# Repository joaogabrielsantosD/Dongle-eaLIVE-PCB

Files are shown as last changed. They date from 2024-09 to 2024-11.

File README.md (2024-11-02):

# Dongle-eaLIVE-PCB

## Hardware
Dongle-eaLIVE has been created using KiCad and all the design files can be found under [01_Specs](01_Specs/) folder (you can see in this folder the [Schematic](01_Specs/01_Schematic/), [LayoutPCB](01_Specs/02_LayoutPCB/) and [3Dmodel](01_Specs/03_3Dmodel/)) , and the  production can be found in [Gerber](02_Gerber&BOM/01_Gerber/) files and the interactive BOM in [BOM](02_Gerber&BOM/02_BOM/00_InteractiveBOM/). Images below shows a quick overview of the hardware design.

| PCB Front |  PCB Back |
| :---: | :---: |
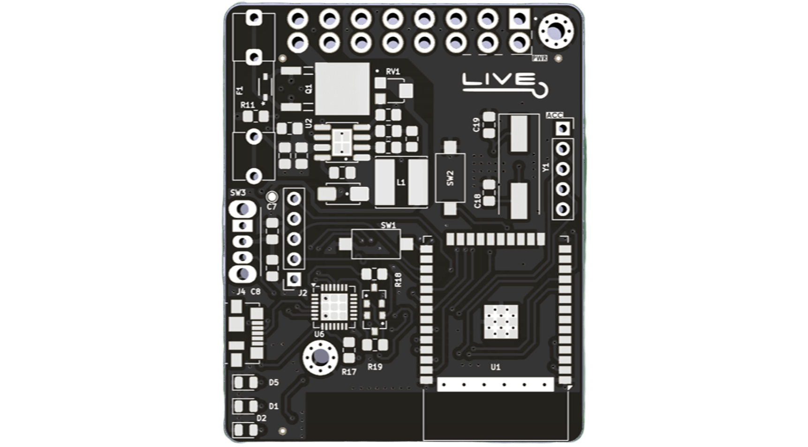
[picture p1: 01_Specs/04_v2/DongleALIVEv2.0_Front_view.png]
Dongle-ealive front
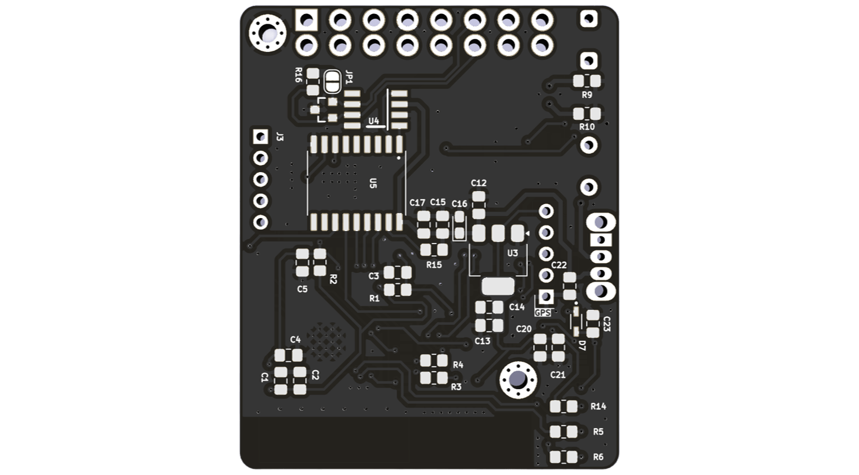
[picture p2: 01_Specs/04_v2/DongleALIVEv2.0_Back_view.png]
Dongle-eavlive back
|   |  |

### Dimensions
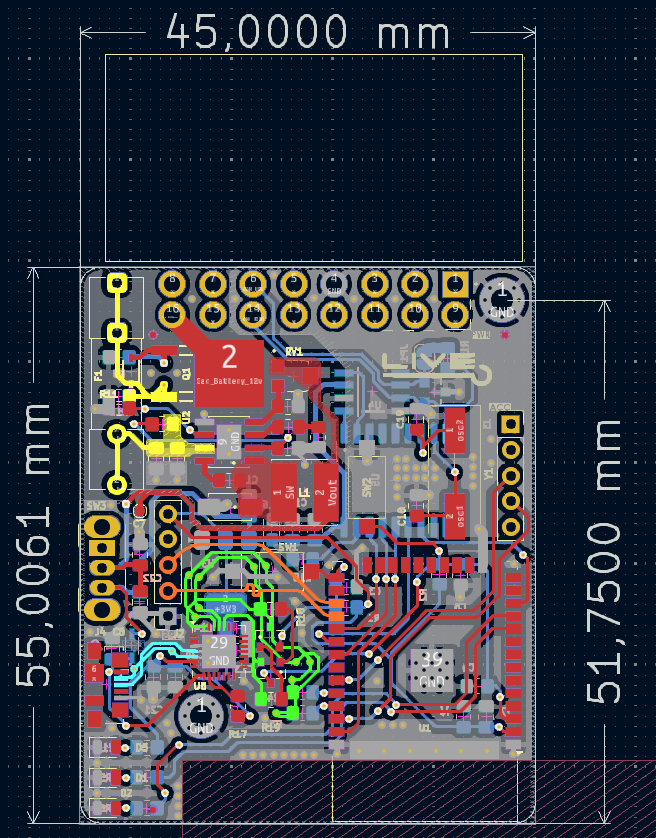
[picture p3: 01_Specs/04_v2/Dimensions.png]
Dongle-ealive dimensions


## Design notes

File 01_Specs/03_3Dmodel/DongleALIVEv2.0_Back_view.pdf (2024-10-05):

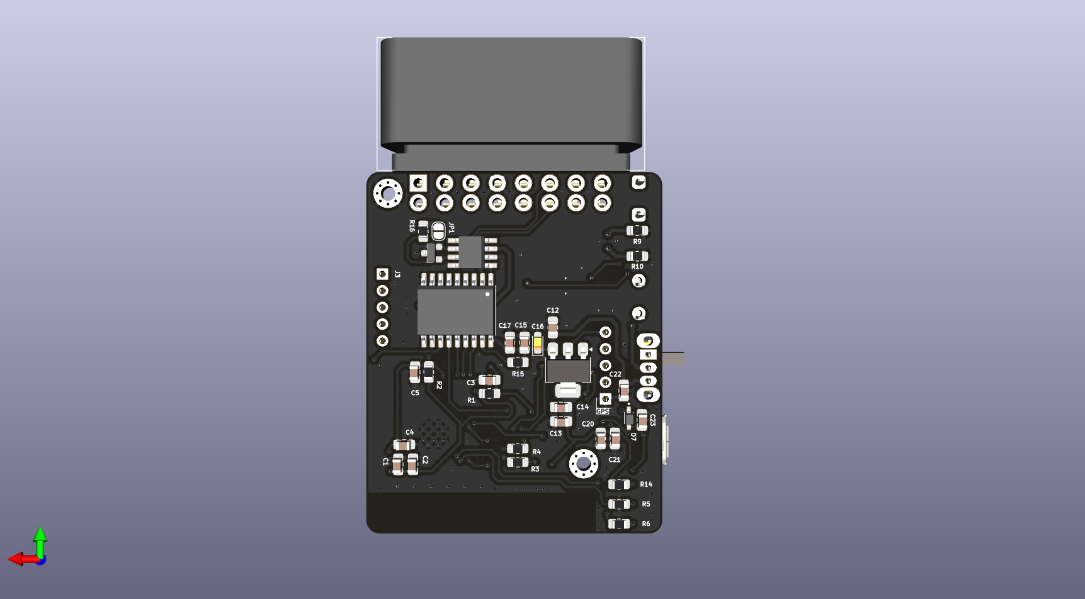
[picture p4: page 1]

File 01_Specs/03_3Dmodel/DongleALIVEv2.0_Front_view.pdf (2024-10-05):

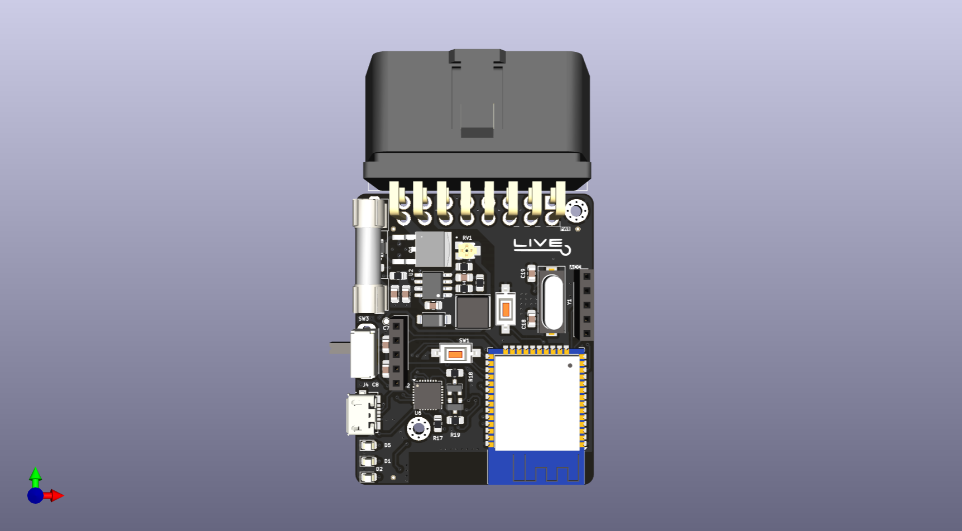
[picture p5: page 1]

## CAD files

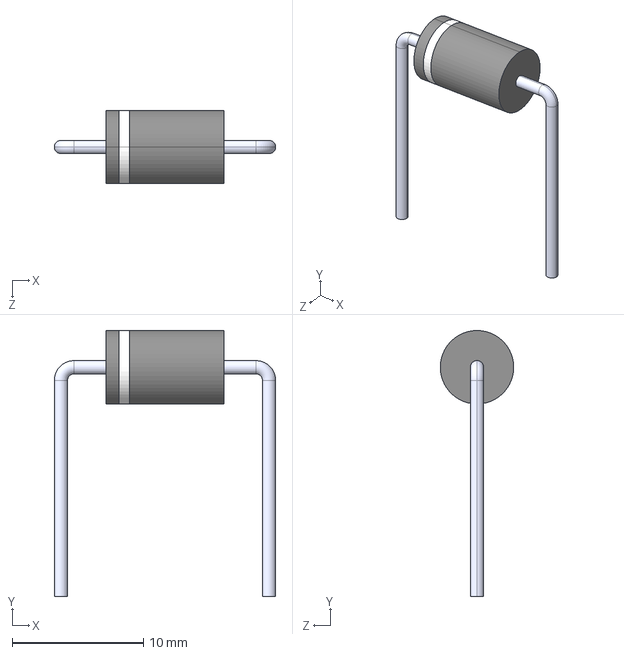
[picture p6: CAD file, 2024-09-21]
03_Libraries/03_3Dmodels/1.5KE16A/1.5KE16A.step
16.9 x 20.3 x 5.60 mm

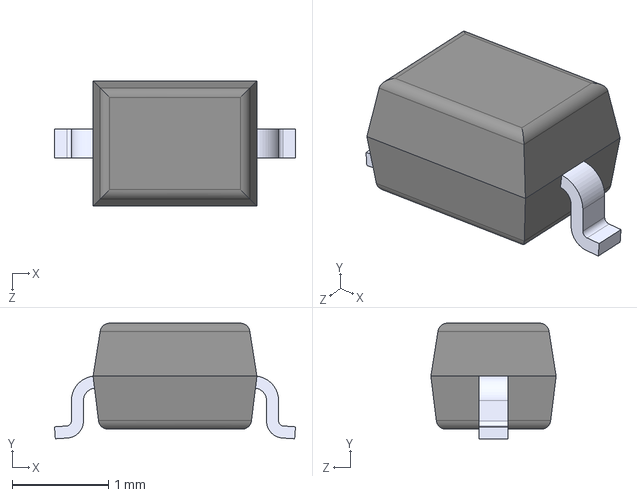
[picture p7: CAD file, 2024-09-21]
03_Libraries/03_3Dmodels/BAT760-7/BAT760-7.step
2.50 x 1.20 x 1.30 mm

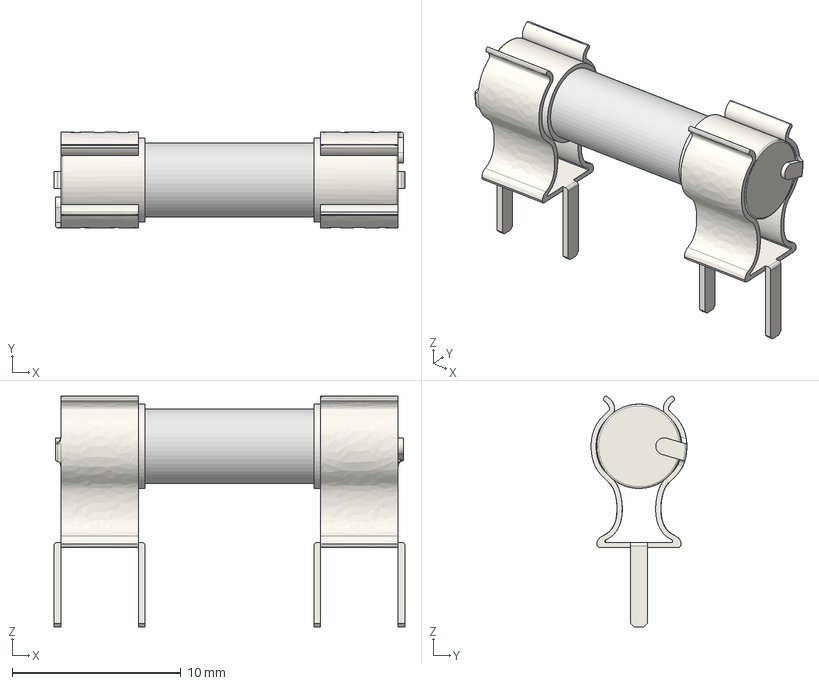
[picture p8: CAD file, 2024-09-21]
03_Libraries/03_3Dmodels/Fuse/FuseHolder 5x20mm.step
20.8 x 5.68 x 13.7 mm

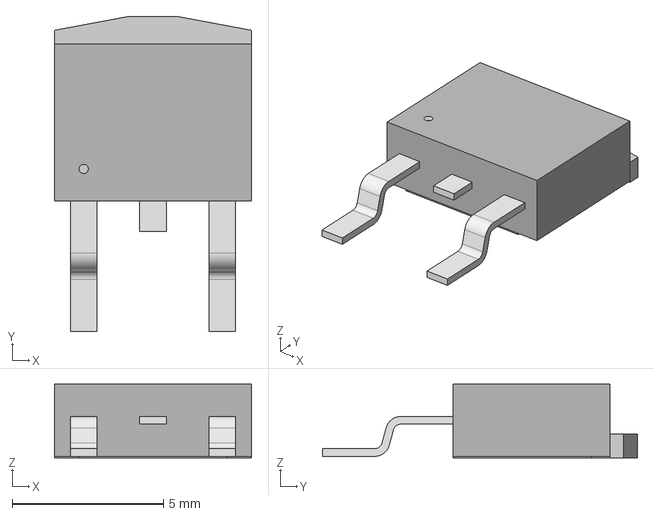
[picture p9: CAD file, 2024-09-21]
03_Libraries/03_3Dmodels/IRF5305S/IRF5305S.step
6.53 x 10.4 x 2.44 mm

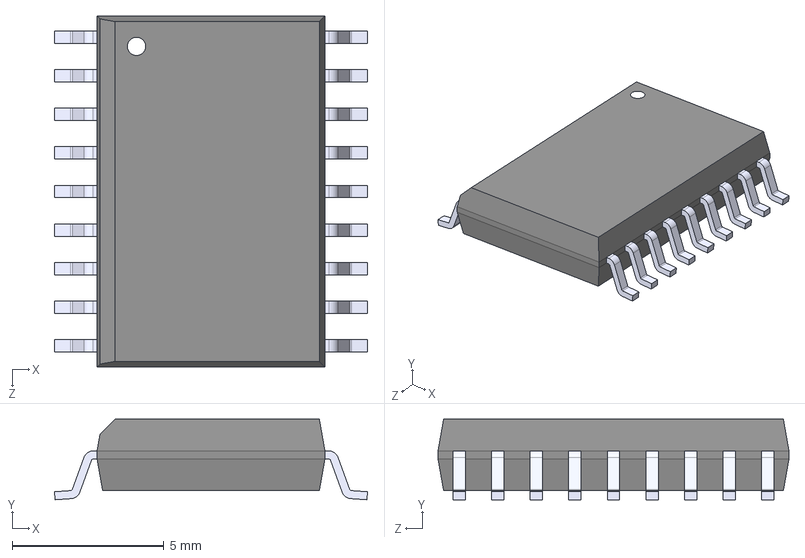
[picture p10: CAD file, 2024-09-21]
03_Libraries/03_3Dmodels/MCP2515/MCP2515-I_SO.step
10.3 x 2.65 x 11.5 mm

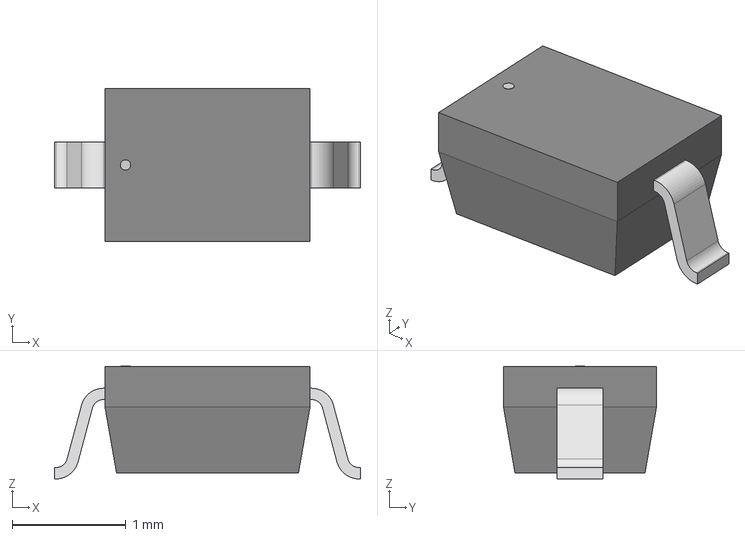
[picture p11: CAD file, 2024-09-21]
03_Libraries/03_3Dmodels/MM3Z10VT1G/MM3Z10VT1G.step
2.69 x 1.35 x 0.993 mm

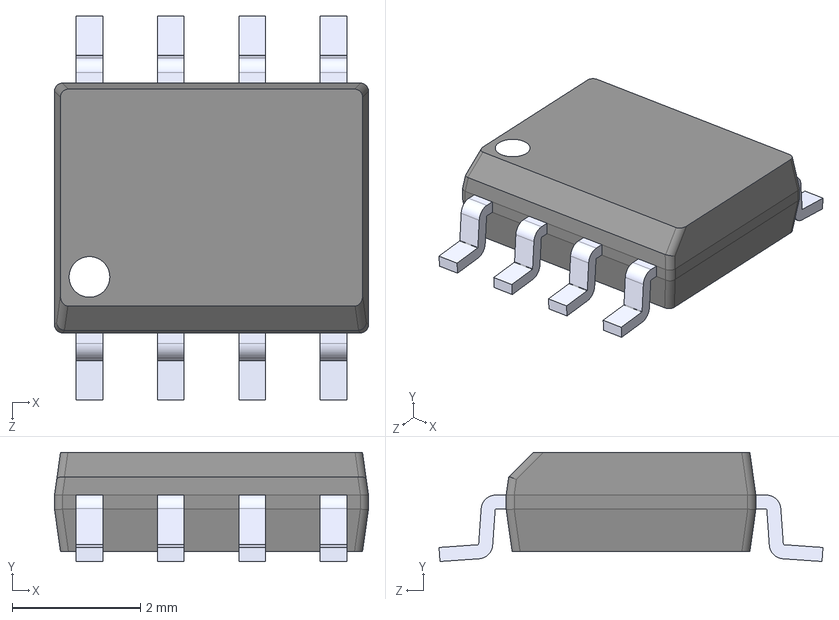
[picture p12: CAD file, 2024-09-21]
03_Libraries/03_3Dmodels/MP1584EN/MP1584EN.step
4.90 x 1.70 x 5.99 mm

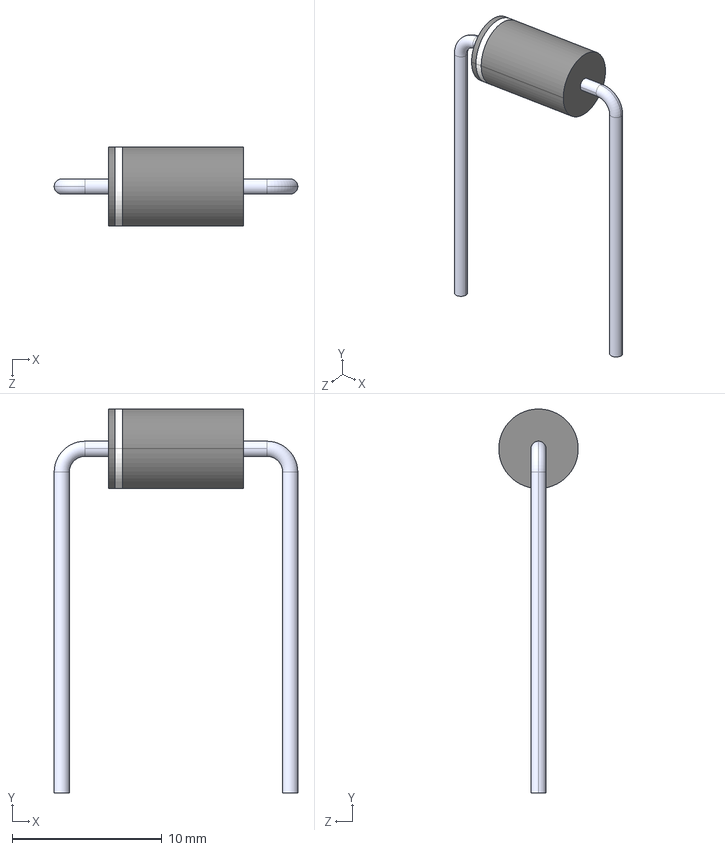
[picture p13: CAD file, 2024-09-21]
03_Libraries/03_3Dmodels/MUR460/MUR460.step
16.3 x 25.6 x 5.30 mm

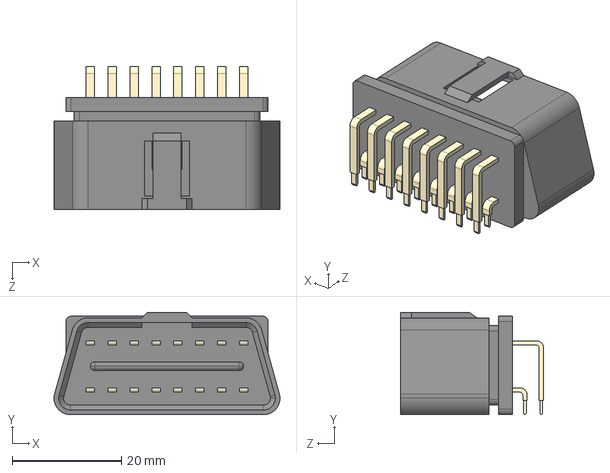
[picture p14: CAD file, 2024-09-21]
03_Libraries/03_3Dmodels/OBDII_Connector/C-OBD-II-16M--3DModel-STEP-1.STEP
41.3 x 18.7 x 26.2 mm

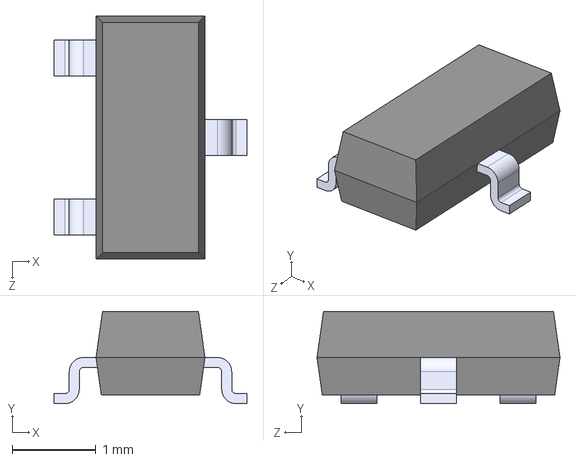
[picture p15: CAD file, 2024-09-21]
03_Libraries/03_3Dmodels/PESD1CAN/PESD1CAN.step
2.30 x 1.10 x 2.90 mm

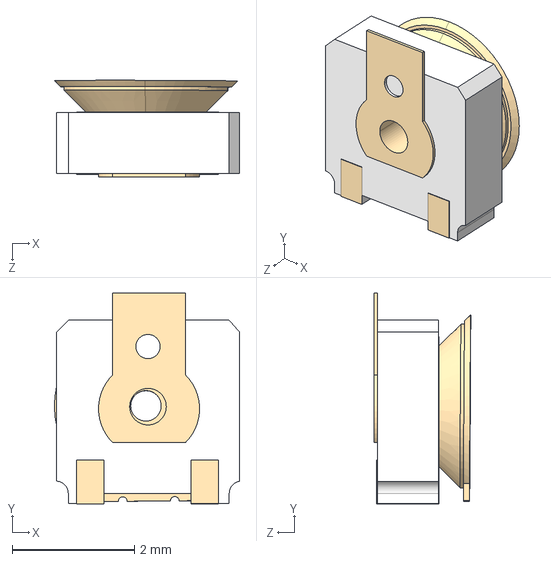
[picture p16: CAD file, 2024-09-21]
03_Libraries/03_3Dmodels/Potenciometer_SMD/35WR10KLFTR.step
3.03 x 3.46 x 1.58 mm
pot1.1
pot.2

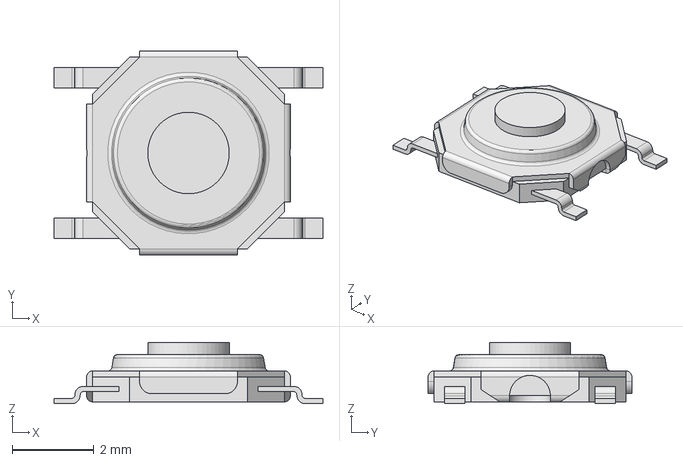
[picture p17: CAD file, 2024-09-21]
03_Libraries/03_3Dmodels/Push_Botton_SMD/TL3342F160QG.step
6.60 x 5.00 x 1.50 mm

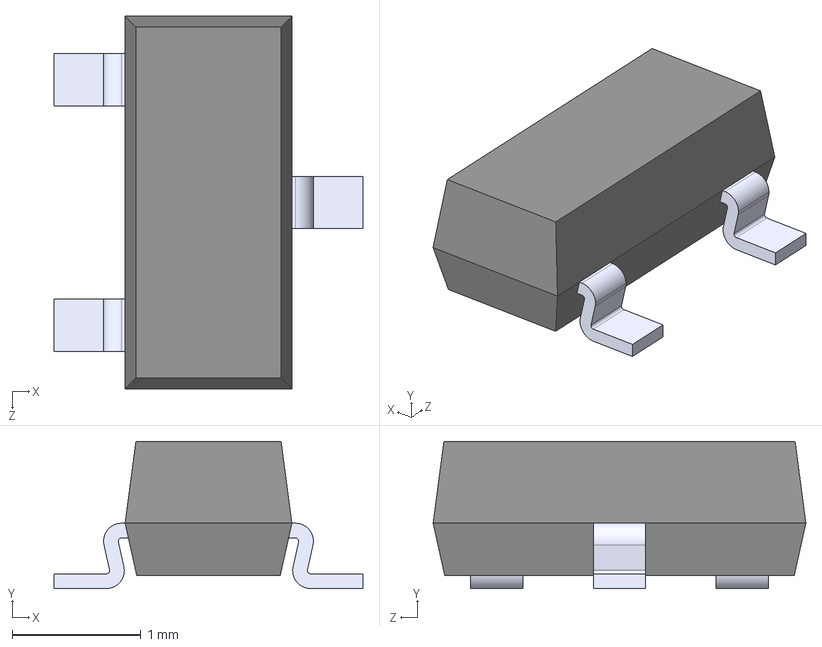
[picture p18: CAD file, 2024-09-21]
03_Libraries/03_3Dmodels/S8050/SS8050-G.step
2.40 x 1.14 x 2.90 mm

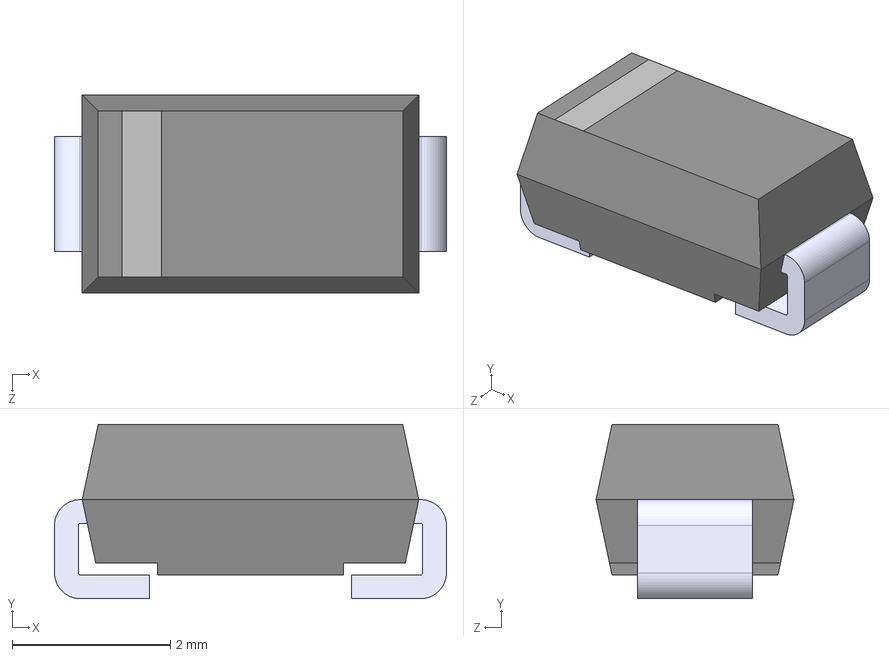
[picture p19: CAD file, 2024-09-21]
03_Libraries/03_3Dmodels/SS34/SS34-HF.step
4.95 x 2.20 x 2.50 mm

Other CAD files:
03_Libraries/03_3Dmodels/TJA1050T/TJA1050.step

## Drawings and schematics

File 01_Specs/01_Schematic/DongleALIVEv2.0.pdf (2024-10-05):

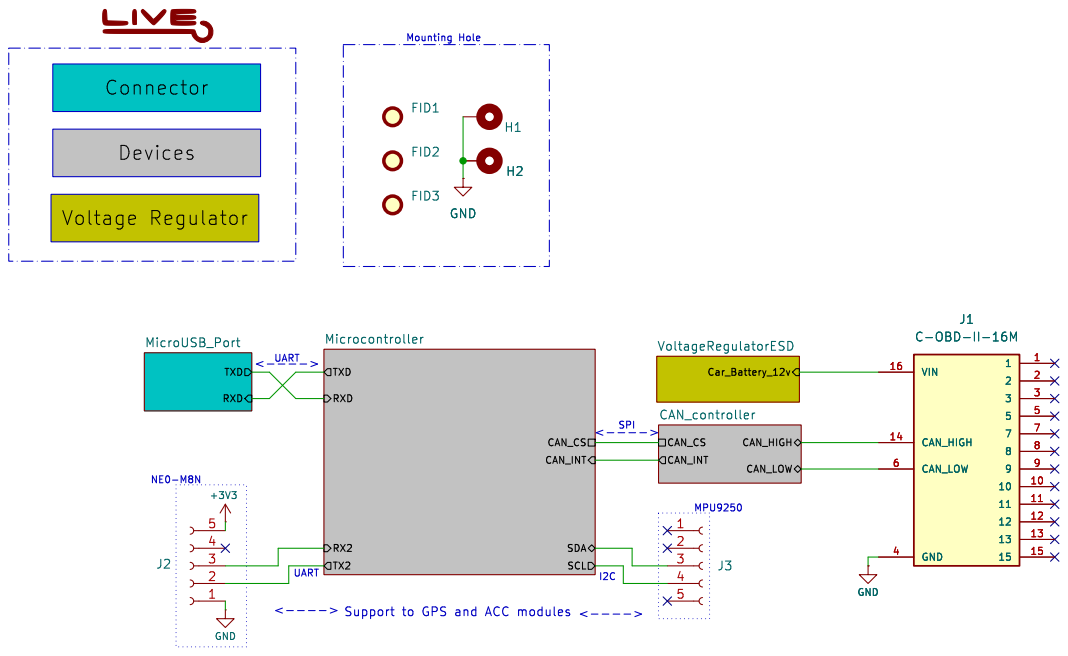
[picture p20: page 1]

Id: 1/5 Title: Dongle eaLIVE for telemetry

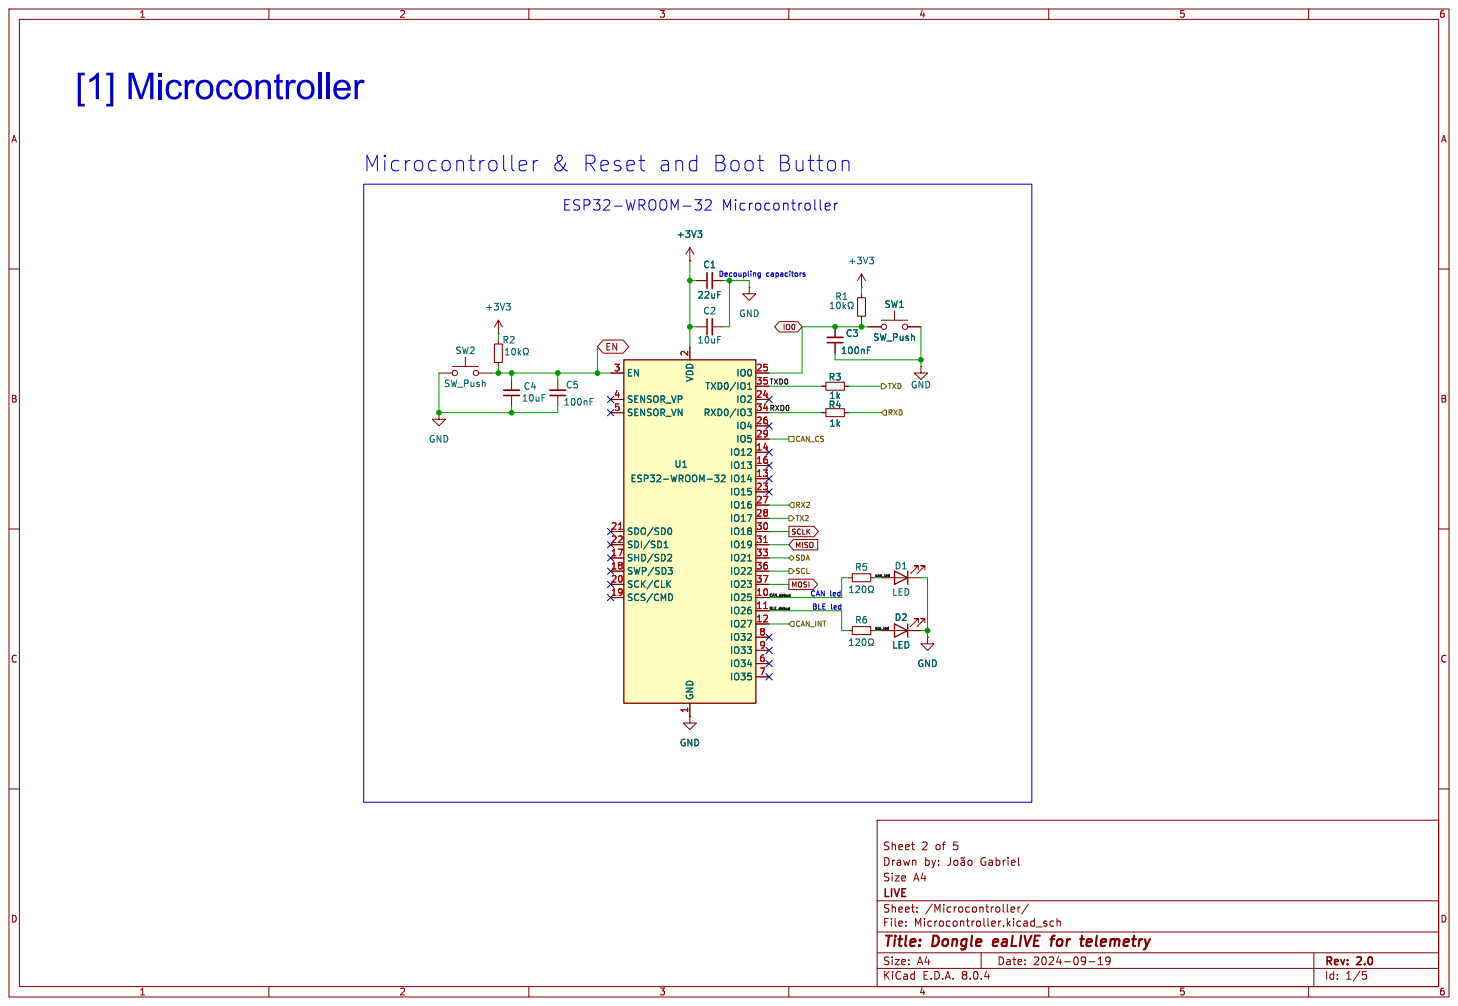
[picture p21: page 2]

TX2 CAN_CS RX2 MISO MOSI SCLK EN

2 SCK/CLK 20 SDO/SD0 21 SDI/SD1 22

File: Microcontroller.kicad_sch Sheet: /Microcontroller/ LIVE

Id: 1/5 Title: Dongle eaLIVE for telemetry

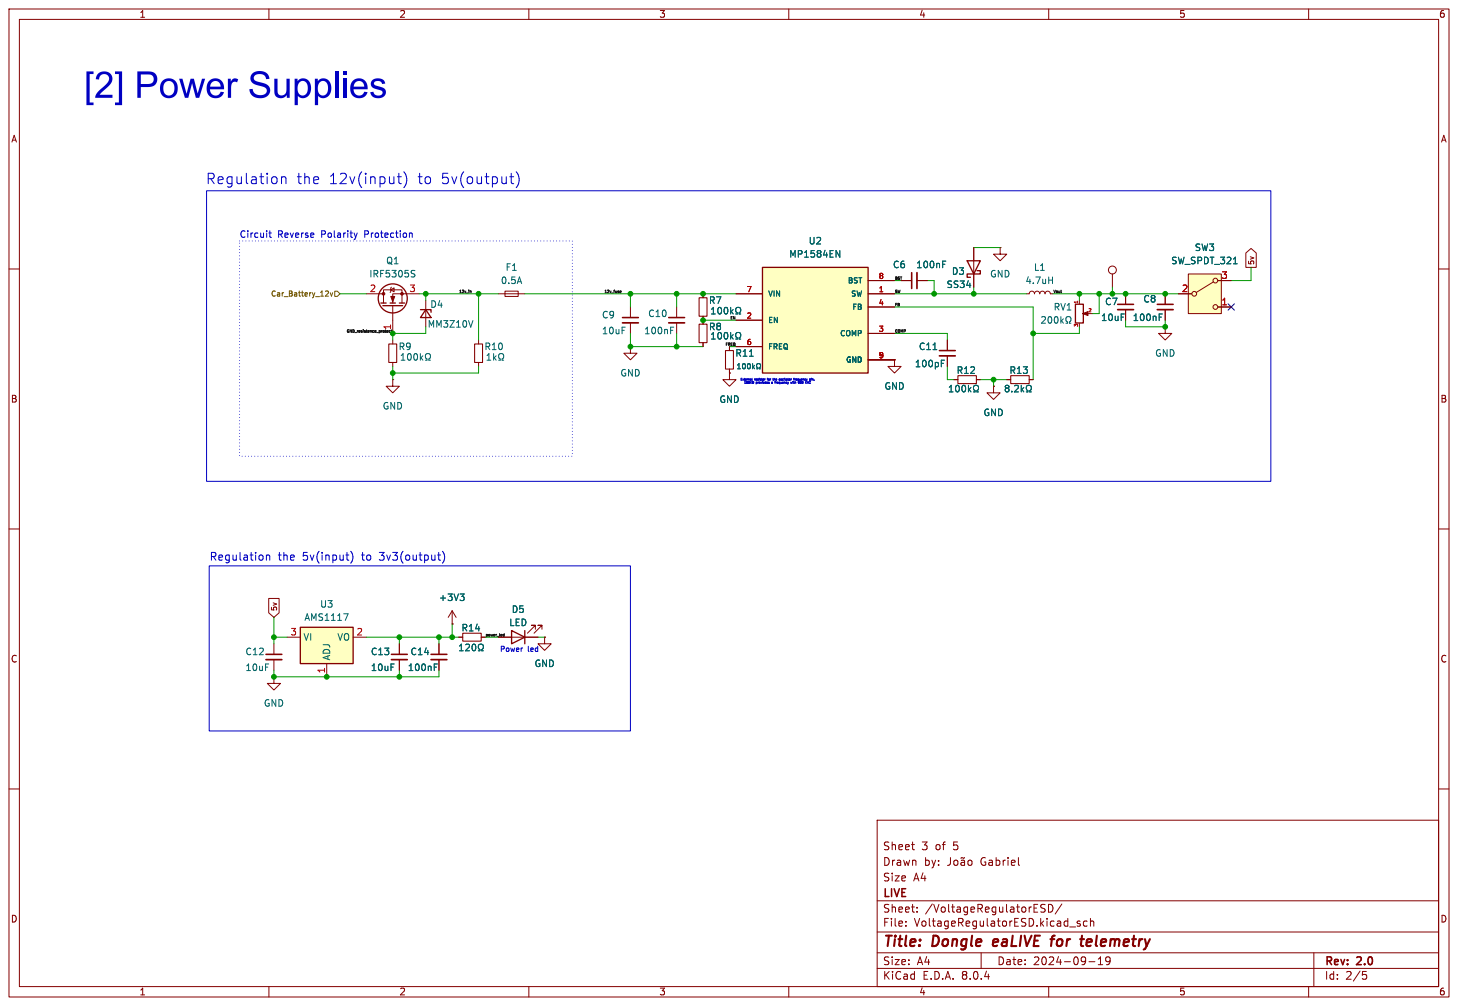
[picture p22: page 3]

File: VoltageRegulatorESD.kicad_sch Sheet: /VoltageRegulatorESD/ LIVE

Id: 2/5 Title: Dongle eaLIVE for telemetry

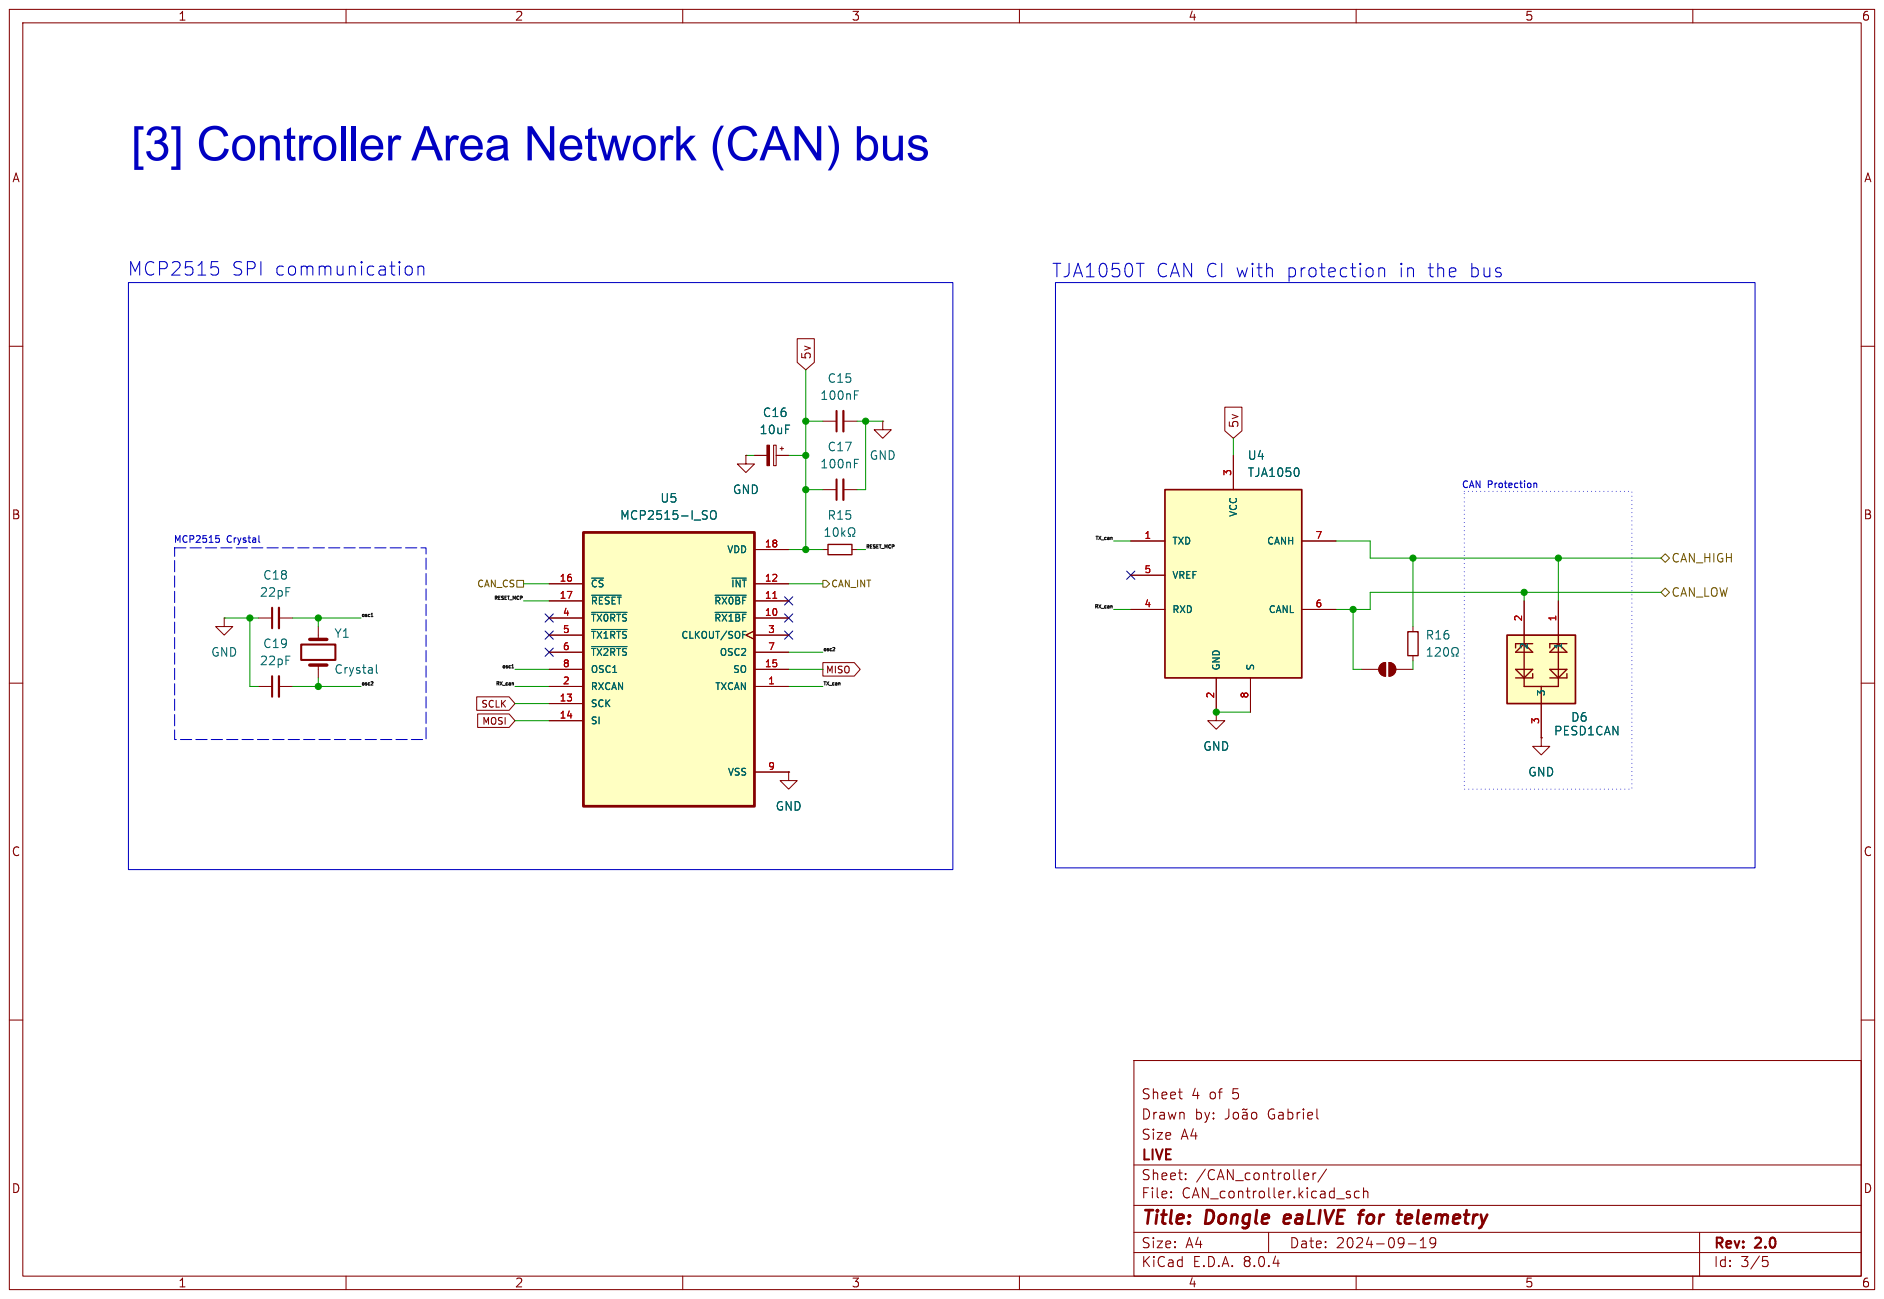
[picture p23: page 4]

[3] Controller Area Network (CAN) bus

3 RXD 4 VREF 5 CANL 6 CANH 7 S

Id: 3/5 Title: Dongle eaLIVE for telemetry

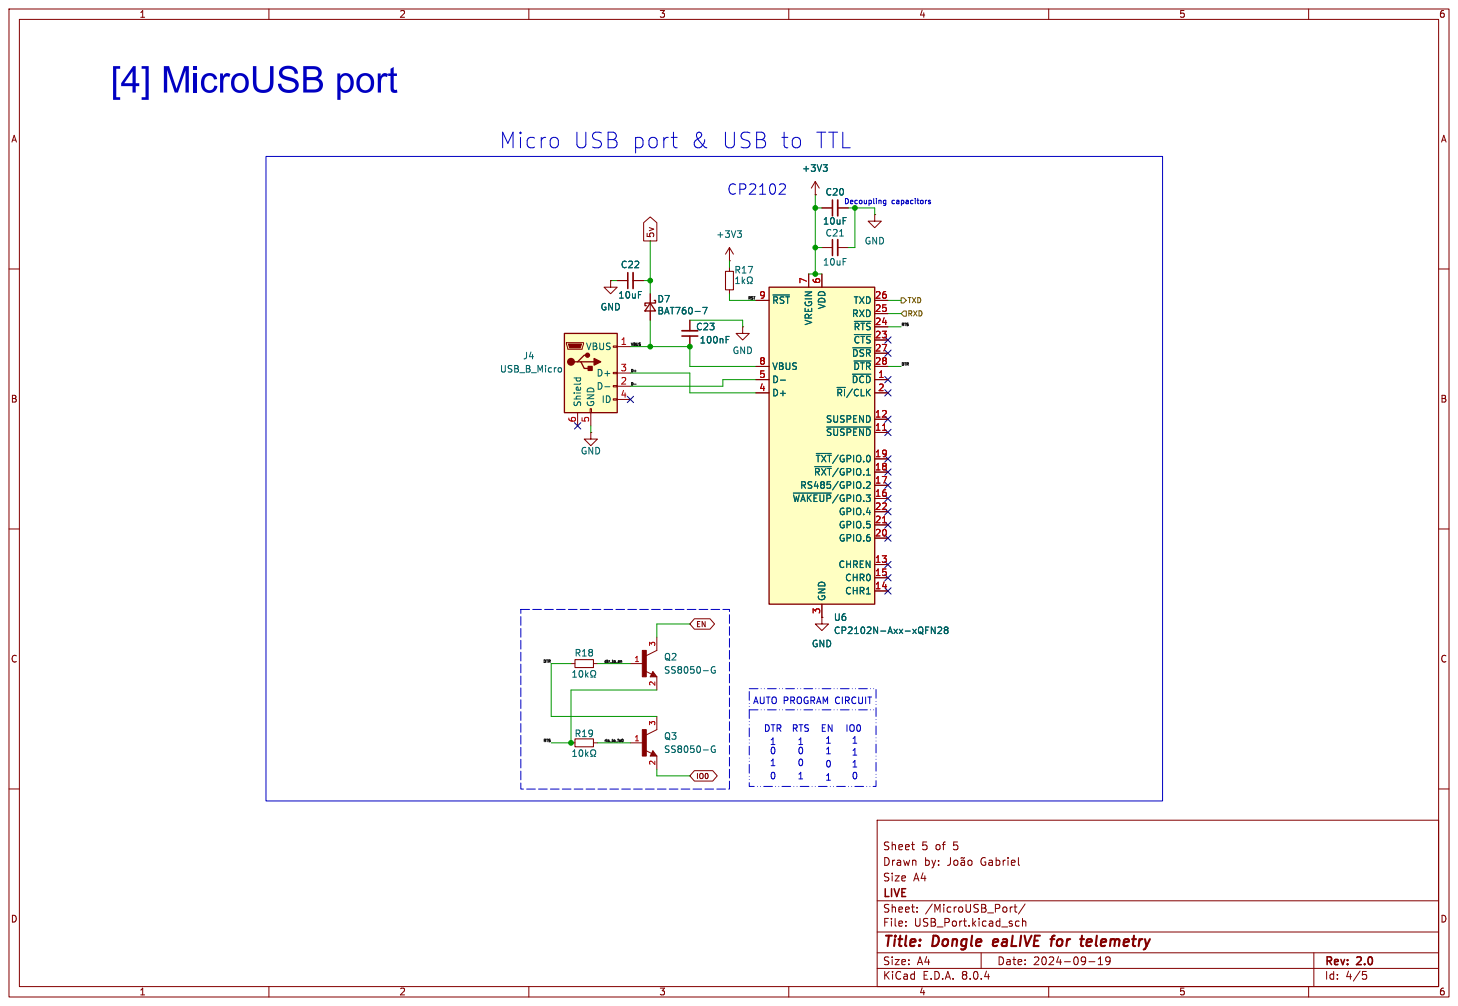
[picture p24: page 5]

1 Micro USB port & USB to TTL
DTR 0

7 VBUS 8 ~{RST} 9 U6 CP2102N-Axx-xQFN28 GND

Id: 4/5 Title: Dongle eaLIVE for telemetry

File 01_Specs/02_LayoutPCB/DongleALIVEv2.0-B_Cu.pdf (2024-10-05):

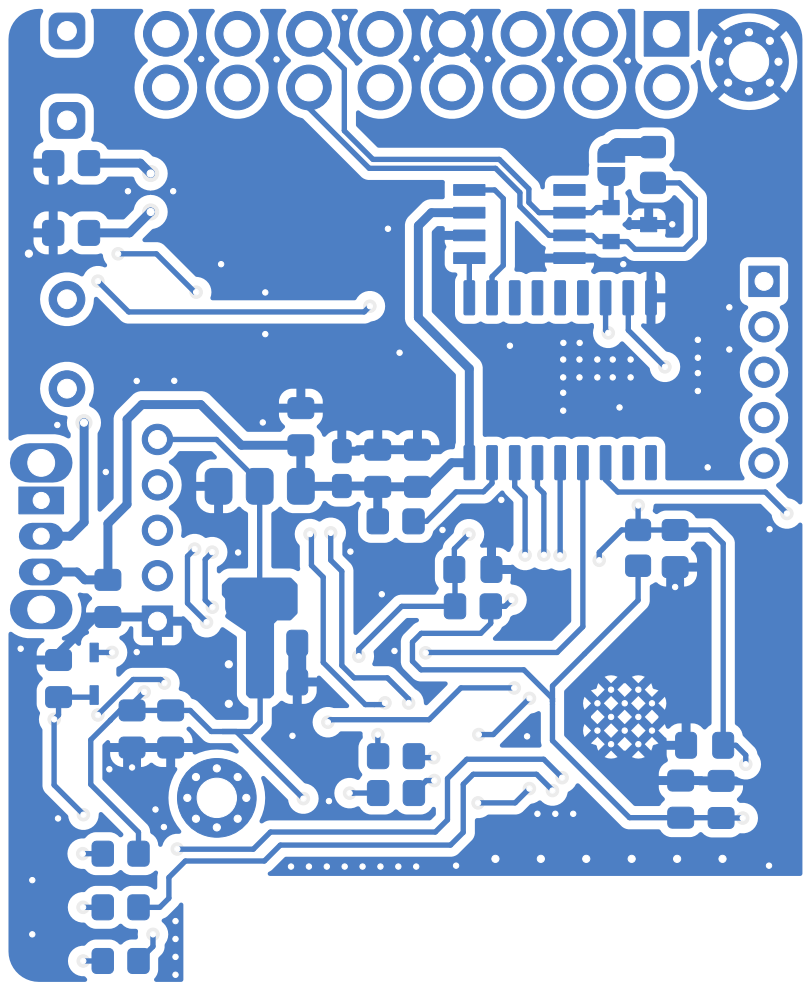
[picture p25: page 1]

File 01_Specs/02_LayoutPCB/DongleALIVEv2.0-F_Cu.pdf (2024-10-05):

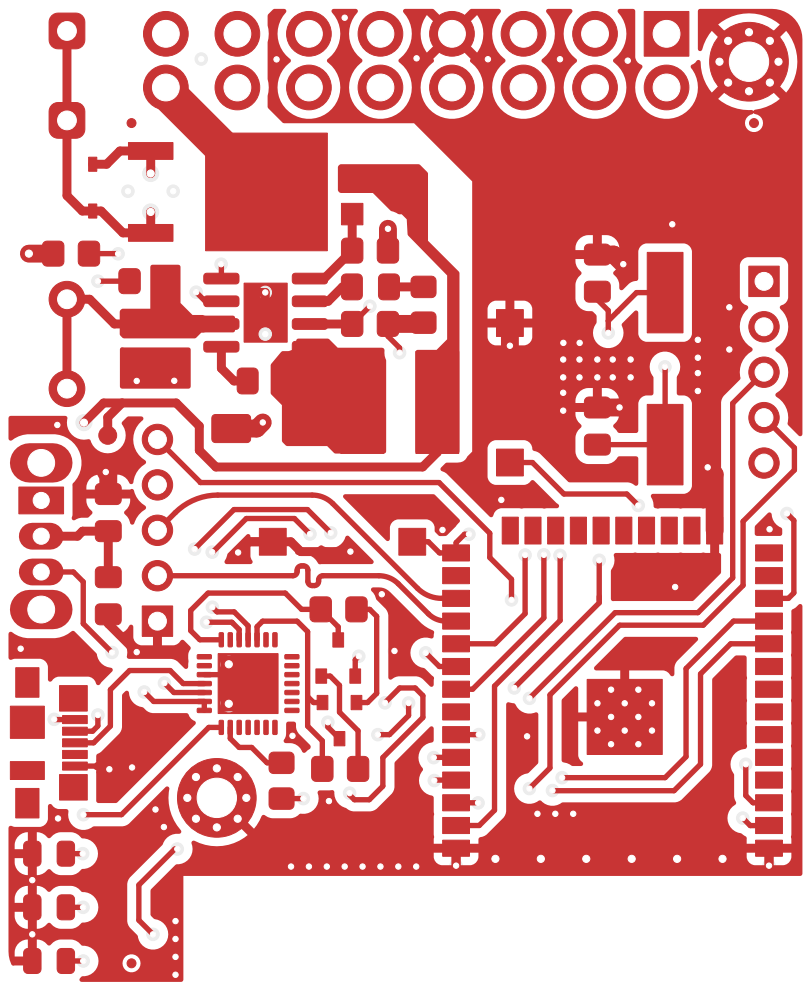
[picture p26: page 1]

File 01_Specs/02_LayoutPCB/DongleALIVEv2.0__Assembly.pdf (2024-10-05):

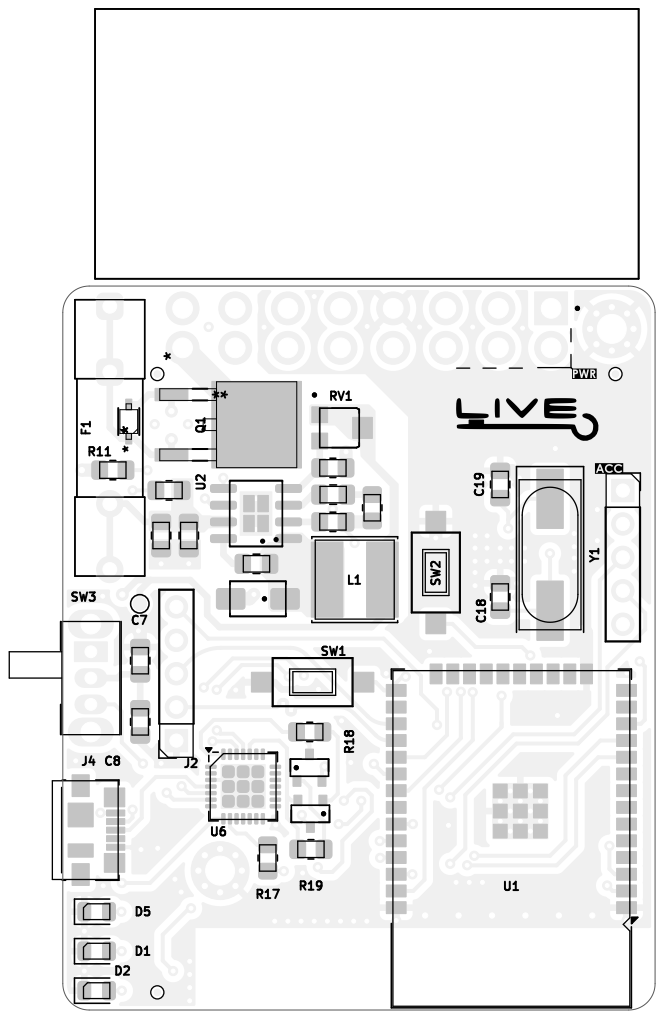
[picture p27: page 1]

Id: 1/1 Title: Dongle eaLIVE for telemetry

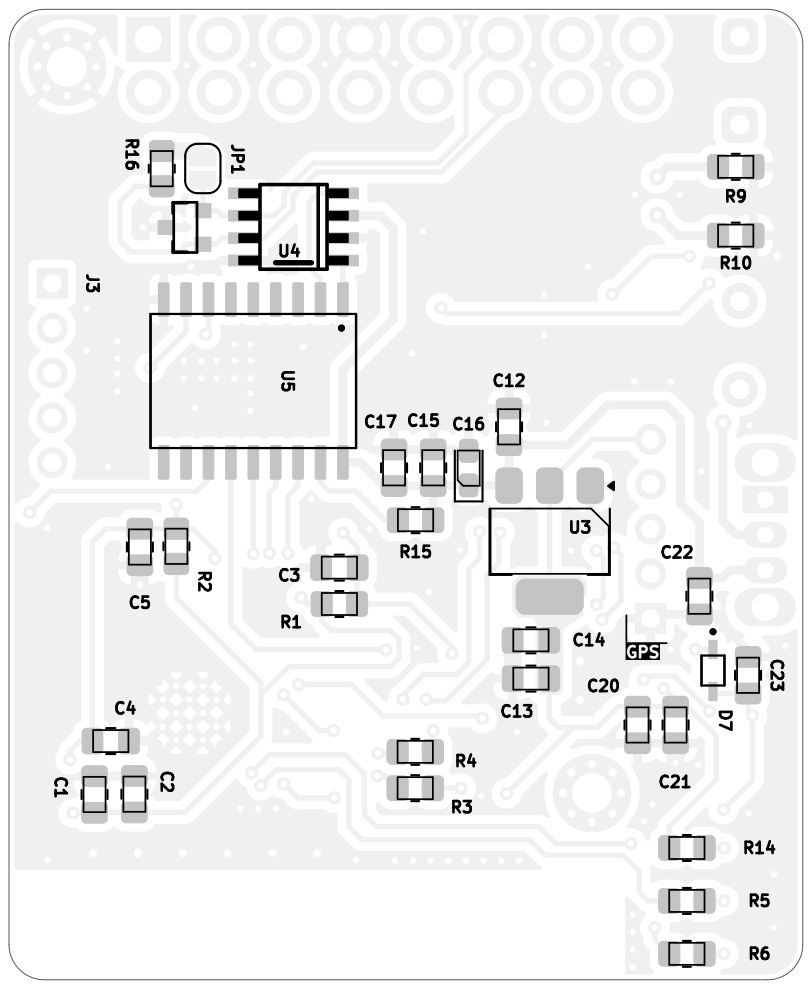
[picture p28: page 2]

Id: 1/1 Title: Dongle eaLIVE for telemetry

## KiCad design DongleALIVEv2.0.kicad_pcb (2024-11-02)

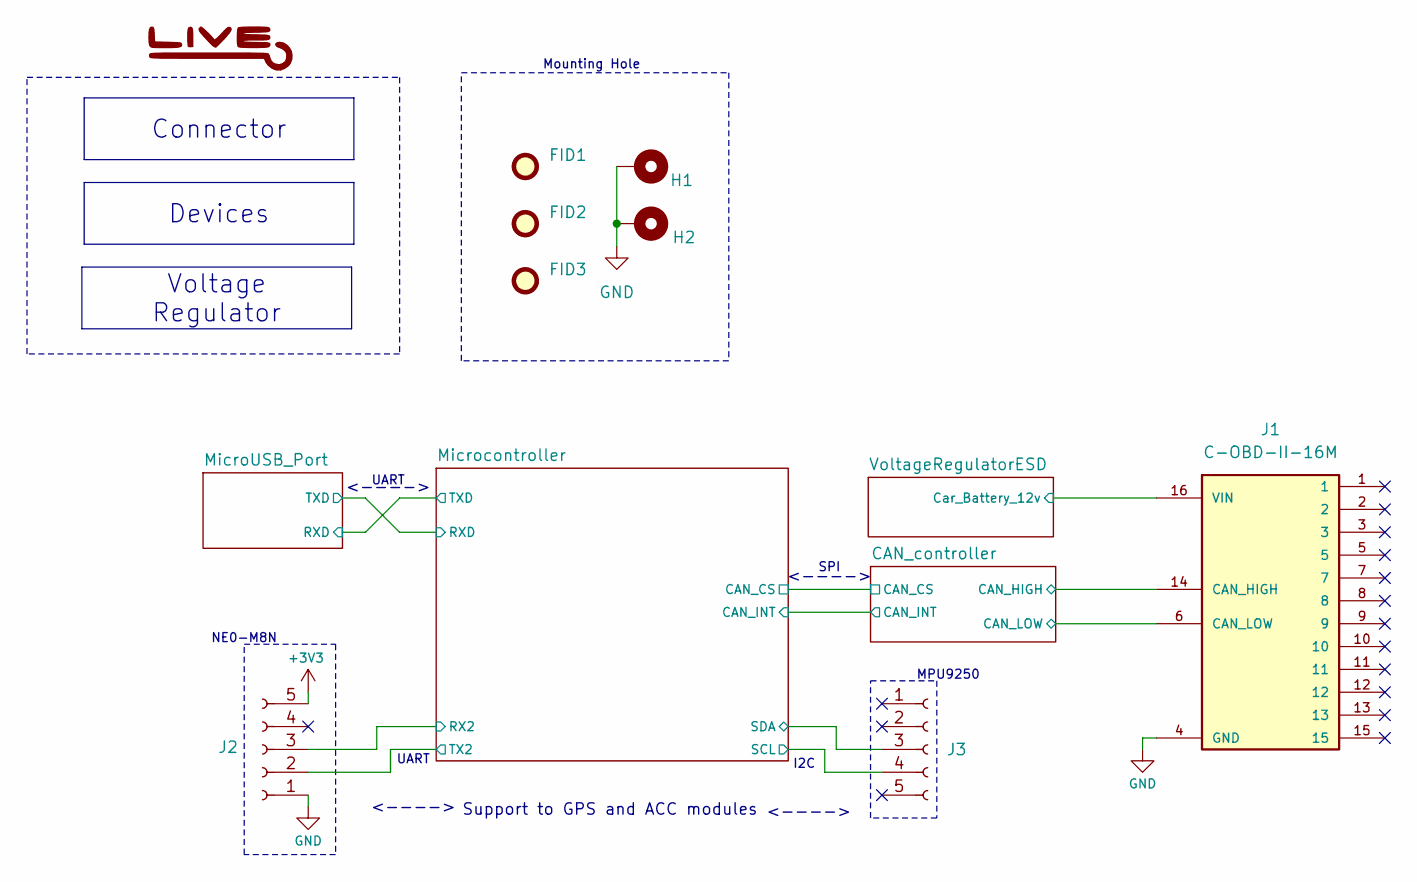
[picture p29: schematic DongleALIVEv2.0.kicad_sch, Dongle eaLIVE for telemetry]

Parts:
FID1, FID2, FID3: Fiducial; Fiducial_0.5mm_Mask1mm
H1, H2: MountingHole_Pad; MountingHole_2.2mm_M2_Pad_Via
J1: C-OBD-II-16M; COMTECH_C-OBD-II-16M
J2, J3: Conn_01x05_Socket; PinSocket_1x05_P2.54mm_Vertical; LCSC C16076298

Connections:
+3V3: J2.5; also elsewhere on the board
/CAN_controller/CAN_HIGH: J1.14 (CAN_HIGH); also elsewhere on the board
/CAN_controller/CAN_LOW: J1.6 (CAN_LOW); also elsewhere on the board
/Microcontroller/RX2: J2.3; also elsewhere on the board
/Microcontroller/SCL: J3.4; also elsewhere on the board
/Microcontroller/SDA: J3.3; also elsewhere on the board
/Microcontroller/TX2: J2.2; also elsewhere on the board
/VoltageRegulatorESD/Car_Battery_12v: J1.16 (VIN); also elsewhere on the board
GND: H1.1, H2.1, J1.4 (GND), J2.1; also elsewhere on the board

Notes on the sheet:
Connector
Voltage Regulator
Devices
Mounting Hole
UART
MPU9250
NE0-M8N
<---->
I2C
Support to GPS and ACC modules
SPI

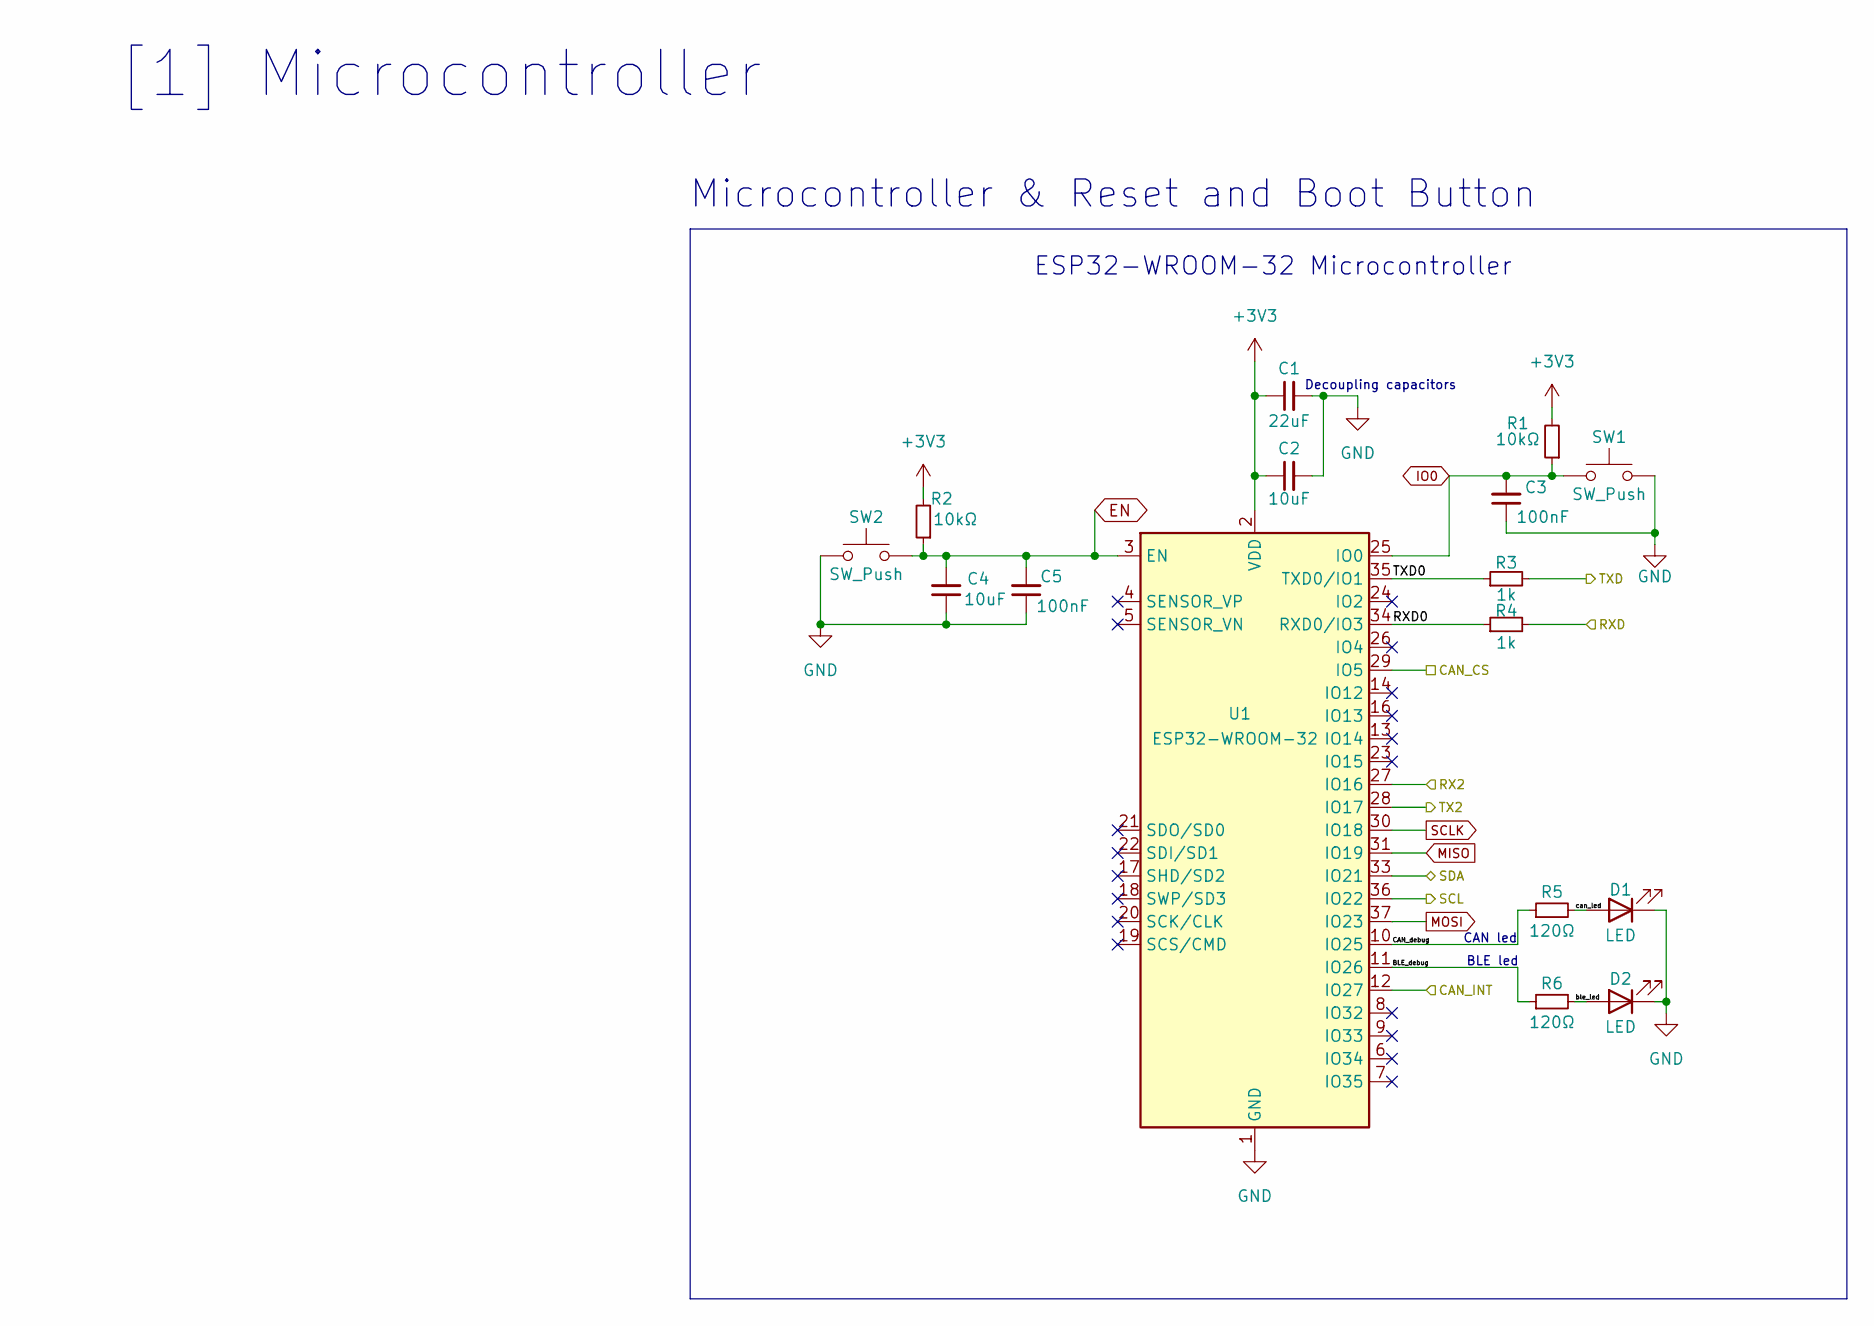
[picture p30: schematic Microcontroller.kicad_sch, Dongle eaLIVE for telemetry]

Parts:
C1: 22uF; C_0805_2012Metric_Pad1.18x1.45mm_HandSolder; LCSC C105484
C2, C4: 10uF; C_0805_2012Metric_Pad1.18x1.45mm_HandSolder; LCSC C15850
C3, C5: 100nF; C_0805_2012Metric_Pad1.18x1.45mm_HandSolder; LCSC C49678
D1: LED; LED_0805_2012Metric; LCSC C2296
D2: LED; LED_0805_2012Metric; LCSC C34499
R1, R2: 10kΩ; R_0805_2012Metric_Pad1.20x1.40mm_HandSolder; LCSC C191101
R3, R4: 1k; R_0805_2012Metric_Pad1.20x1.40mm_HandSolder; LCSC C17513
R5, R6: 120Ω; R_0805_2012Metric_Pad1.20x1.40mm_HandSolder; LCSC C966144
SW1, SW2: SW_Push; SW_SPST_CK_RS282G05A3; LCSC C483808
U1: ESP32-WROOM-32; LCSC C82899

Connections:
+3V3: C1.1, C2.1, R1.2, R2.2, U1.2 (VDD); also elsewhere on the board
/CAN_controller/CAN_CS: U1.29 (IO5); also elsewhere on the board
/CAN_controller/CAN_INT: U1.12 (IO27); also elsewhere on the board
/MicroUSB_Port/RXD: R3.2; also elsewhere on the board
/MicroUSB_Port/TXD: R4.2; also elsewhere on the board
/Microcontroller/BLE_debug: R6.1, U1.11 (IO26)
/Microcontroller/CAN_debug: R5.1, U1.10 (IO25)
/Microcontroller/RX2: U1.27 (IO16); also elsewhere on the board
/Microcontroller/RXD0: R4.1, U1.34 (RXD0/IO3)
/Microcontroller/SCL: U1.36 (IO22); also elsewhere on the board
/Microcontroller/SDA: U1.33 (IO21); also elsewhere on the board
/Microcontroller/TX2: U1.28 (IO17); also elsewhere on the board
/Microcontroller/TXD0: R3.1, U1.35 (TXD0/IO1)
/Microcontroller/ble_led: D2.2 (A), R6.2
/Microcontroller/can_led: D1.2 (A), R5.2
EN: C4.2, C5.2, R2.1, SW2.2, U1.3 (EN); also elsewhere on the board
GND: C1.2, C2.2, C3.1, C4.1, C5.1, D1.1 (K), D2.1 (K), SW1.2, SW2.1, U1.1 (GND), U1.15 (GND), U1.38 (GND), U1.39 (GND); also elsewhere on the board
IO0: C3.2, R1.1, SW1.1, U1.25 (IO0); also elsewhere on the board
MISO: U1.31 (IO19); also elsewhere on the board
MOSI: U1.37 (IO23); also elsewhere on the board
SCLK: U1.30 (IO18); also elsewhere on the board

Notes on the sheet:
ESP32-WROOM-32 Microcontroller
Microcontroller & Reset and Boot Button
CAN led
[1] Microcontroller
BLE led
Decoupling capacitors

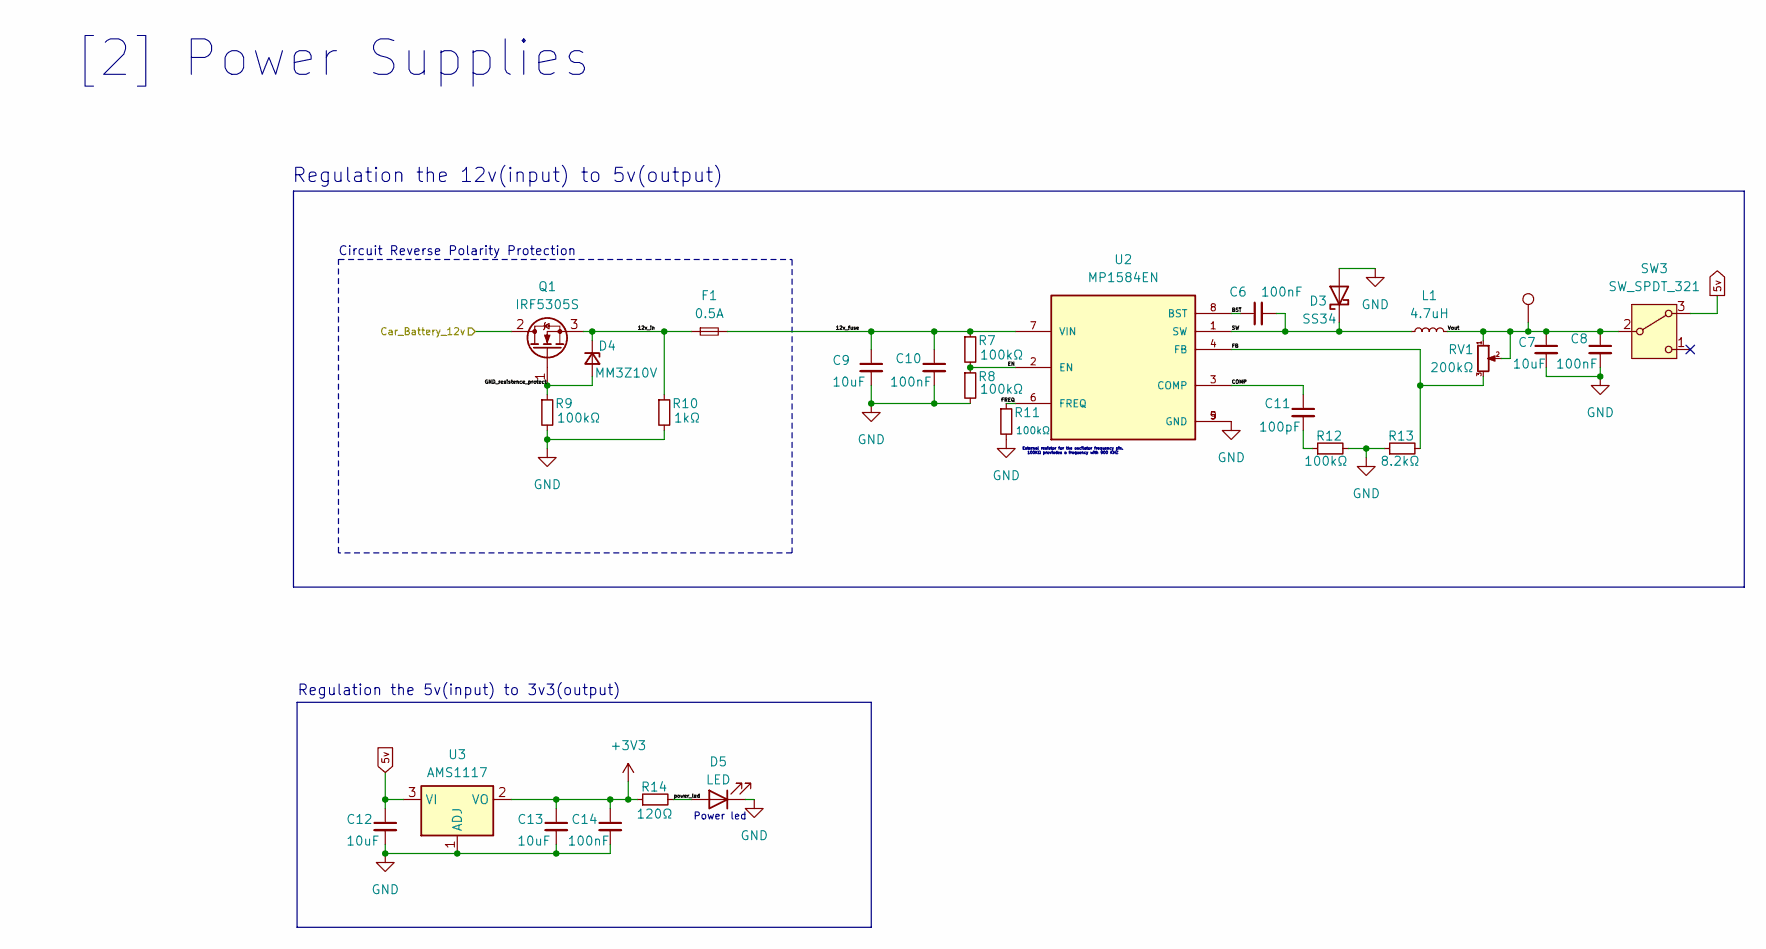
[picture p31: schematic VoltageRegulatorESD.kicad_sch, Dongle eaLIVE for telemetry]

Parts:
C6, C8, C10, C14: 100nF; C_0805_2012Metric_Pad1.18x1.45mm_HandSolder; LCSC C49678
C7, C9, C12, C13: 10uF; C_0805_2012Metric_Pad1.18x1.45mm_HandSolder; LCSC C15850
C11: 100pF; C_0805_2012Metric_Pad1.18x1.45mm_HandSolder; LCSC C1790
D3: SS34; LCSC C8678
D4: MM3Z10V; MM3Z10VT1G; LCSC C39057
D5: LED; LED_0805_2012Metric; LCSC C19171391
F1: 0.5A; Fuseholder_Clip-5x20mm_Littelfuse_111_Inline_P20.00x5.00mm_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
L1: 4.7uH; L_Cenker_CKCS6028; LCSC C108295
Q1: IRF5305S; LCSC C2874634
R7, R8, R9, R11, R12: 100kΩ; R_0805_2012Metric_Pad1.20x1.40mm_HandSolder; LCSC C149504
R10: 1kΩ; R_0805_2012Metric_Pad1.20x1.40mm_HandSolder; LCSC C17513
R13: 8.2kΩ; R_0805_2012Metric_Pad1.20x1.40mm_HandSolder; LCSC C17828
R14: 120Ω; R_0805_2012Metric_Pad1.20x1.40mm_HandSolder; LCSC C966144
RV1: 200kΩ; Potenciometer; LCSC C128551
SW3: SW_SPDT_321; SW_Slide_SPDT_Angled_CK_OS102011MA1Q; LCSC C273393
TP1: TestPoint; TestPoint_Pad_D1.0mm
U2: MP1584EN
U3: AMS1117; SOT-223-3_TabPin2; LCSC C917183

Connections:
5v: C12.1, SW3.3 (A), U3.3 (VI); also elsewhere on the board
+3V3: C13.1, C14.1, R14.1, U3.2 (VO); also elsewhere on the board
/VoltageRegulatorESD/12v_fuse: C9.1, C10.1, F1.2, R7.1, U2.7 (VIN)
/VoltageRegulatorESD/12v_in: D4.1 (K), F1.1, Q1.3 (S), R10.1
/VoltageRegulatorESD/BST: C6.1, U2.8 (BST)
/VoltageRegulatorESD/COMP: C11.1, U2.3 (COMP)
/VoltageRegulatorESD/Car_Battery_12v: Q1.2 (D); also elsewhere on the board
/VoltageRegulatorESD/EN: R7.2, R8.1, U2.2 (EN)
/VoltageRegulatorESD/FB: R13.2, RV1.3, U2.4 (FB)
/VoltageRegulatorESD/FREQ: R11.1, U2.6 (FREQ)
/VoltageRegulatorESD/GND_resistence_protect: D4.2 (A), Q1.1 (G), R9.1
/VoltageRegulatorESD/SW: C6.2, D3.1 (K), L1.1, U2.1 (SW)
/VoltageRegulatorESD/Vout: C7.1, C8.1, L1.2, RV1.1, RV1.2, SW3.2 (B), TP1.1
/VoltageRegulatorESD/power_led: D5.2 (A), R14.2
GND: C7.2, C8.2, C9.2, C10.2, C12.2, C13.2, C14.2, D3.2 (A), D5.1 (K), R8.2, R9.2, R10.2, R11.2, R12.2, R13.1, U2.5 (GND), U2.9 (GND), U3.1 (ADJ); also elsewhere on the board
unnamed: C11.2, R12.1

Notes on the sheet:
Regulation the 12v(input) to 5v(output)
[2] Power Supplies
External resistor for the oscilator frequency pin. 100KΩ proviedes a frequency with 900 KHZ
Power led
Regulation the 5v(input) to 3v3(output)
Circuit Reverse Polarity Protection

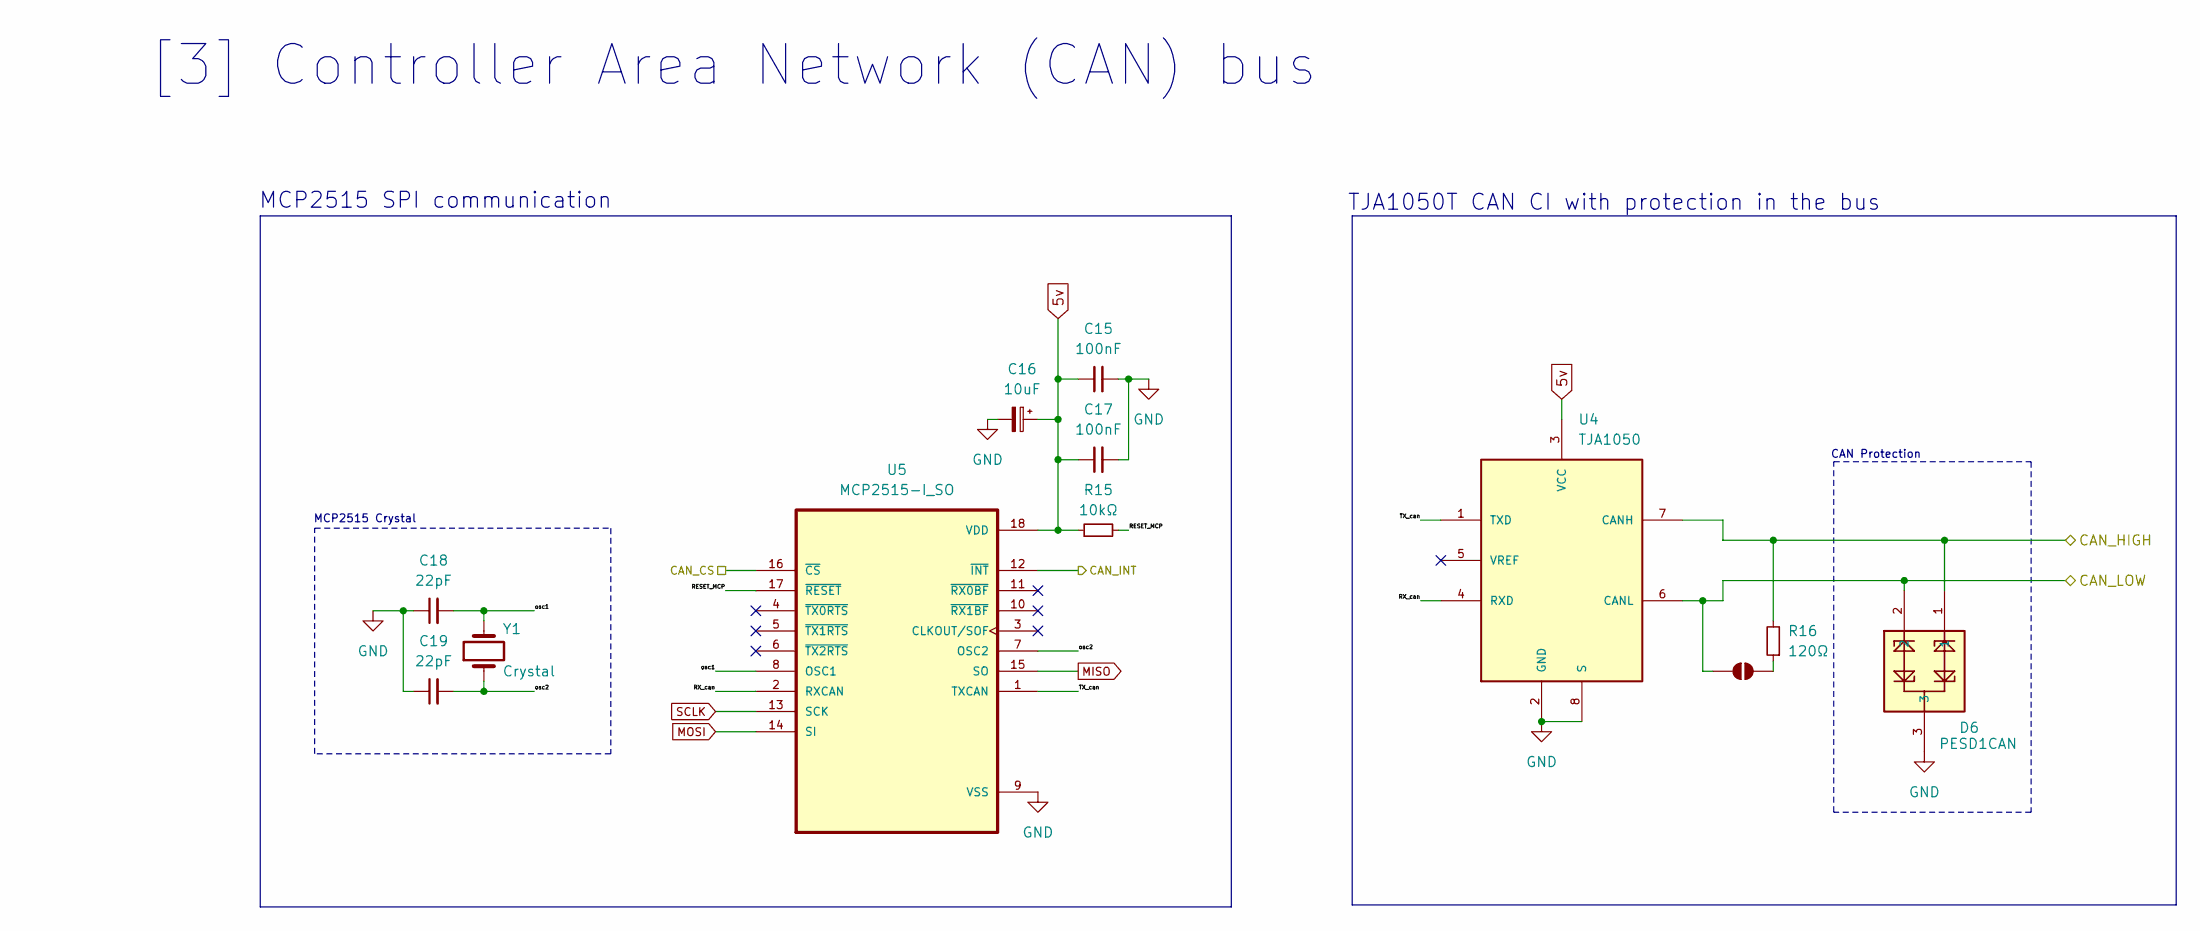
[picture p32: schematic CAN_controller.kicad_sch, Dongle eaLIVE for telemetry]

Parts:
C15, C17: 100nF; C_0805_2012Metric_Pad1.18x1.45mm_HandSolder; LCSC C49678
C16: 10uF; CP_EIA-2012-12_Kemet-R_Pad1.30x1.05mm_HandSolder; LCSC C201218
C18, C19: 22pF; C_0805_2012Metric_Pad1.18x1.45mm_HandSolder; LCSC C157623
D6: PESD1CAN; LCSC C343993
JP1: SolderJumper_2_Open; SolderJumper-2_P1.3mm_Open_RoundedPad1.0x1.5mm
R15: 10kΩ; R_0805_2012Metric_Pad1.20x1.40mm_HandSolder; LCSC C191101
R16: 120Ω; R_0805_2012Metric_Pad1.20x1.40mm_HandSolder; LCSC C966144
U4: TJA1050; TJA1050T; LCSC C6952
U5: MCP2515-I_SO; MCP2515; LCSC C5250735
Y1: Crystal; Crystal_SMD_HC49-SD; LCSC C252310

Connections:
5v: C15.1, C16.1, C17.1, R15.1, U4.3 (VCC), U5.18 (VDD); also elsewhere on the board
/CAN_controller/CAN_CS: U5.16 (~CS); also elsewhere on the board
/CAN_controller/CAN_HIGH: D6.1, R16.2, U4.7 (CANH); also elsewhere on the board
/CAN_controller/CAN_INT: U5.12 (~INT); also elsewhere on the board
/CAN_controller/CAN_LOW: D6.2, JP1.1 (A), U4.6 (CANL); also elsewhere on the board
/CAN_controller/RESET_MCP: R15.2, U5.17 (~RESET)
/CAN_controller/RX_can: U4.4 (RXD), U5.2 (RXCAN)
/CAN_controller/TX_can: U4.1 (TXD), U5.1 (TXCAN)
/CAN_controller/osc1: C18.2, U5.8 (OSC1), Y1.2
/CAN_controller/osc2: C19.2, U5.7 (OSC2), Y1.1
GND: C15.2, C16.2, C17.2, C18.1, C19.1, D6.3, U4.2 (GND), U4.8 (S), U5.9 (VSS); also elsewhere on the board
MISO: U5.15 (SO); also elsewhere on the board
MOSI: U5.14 (SI); also elsewhere on the board
unnamed: JP1.2 (B), R16.1
SCLK: U5.13 (SCK); also elsewhere on the board

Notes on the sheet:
MCP2515 Crystal
MCP2515 SPI communication
TJA1050T CAN CI with protection in the bus
[3] Controller Area Network (CAN) bus
CAN Protection

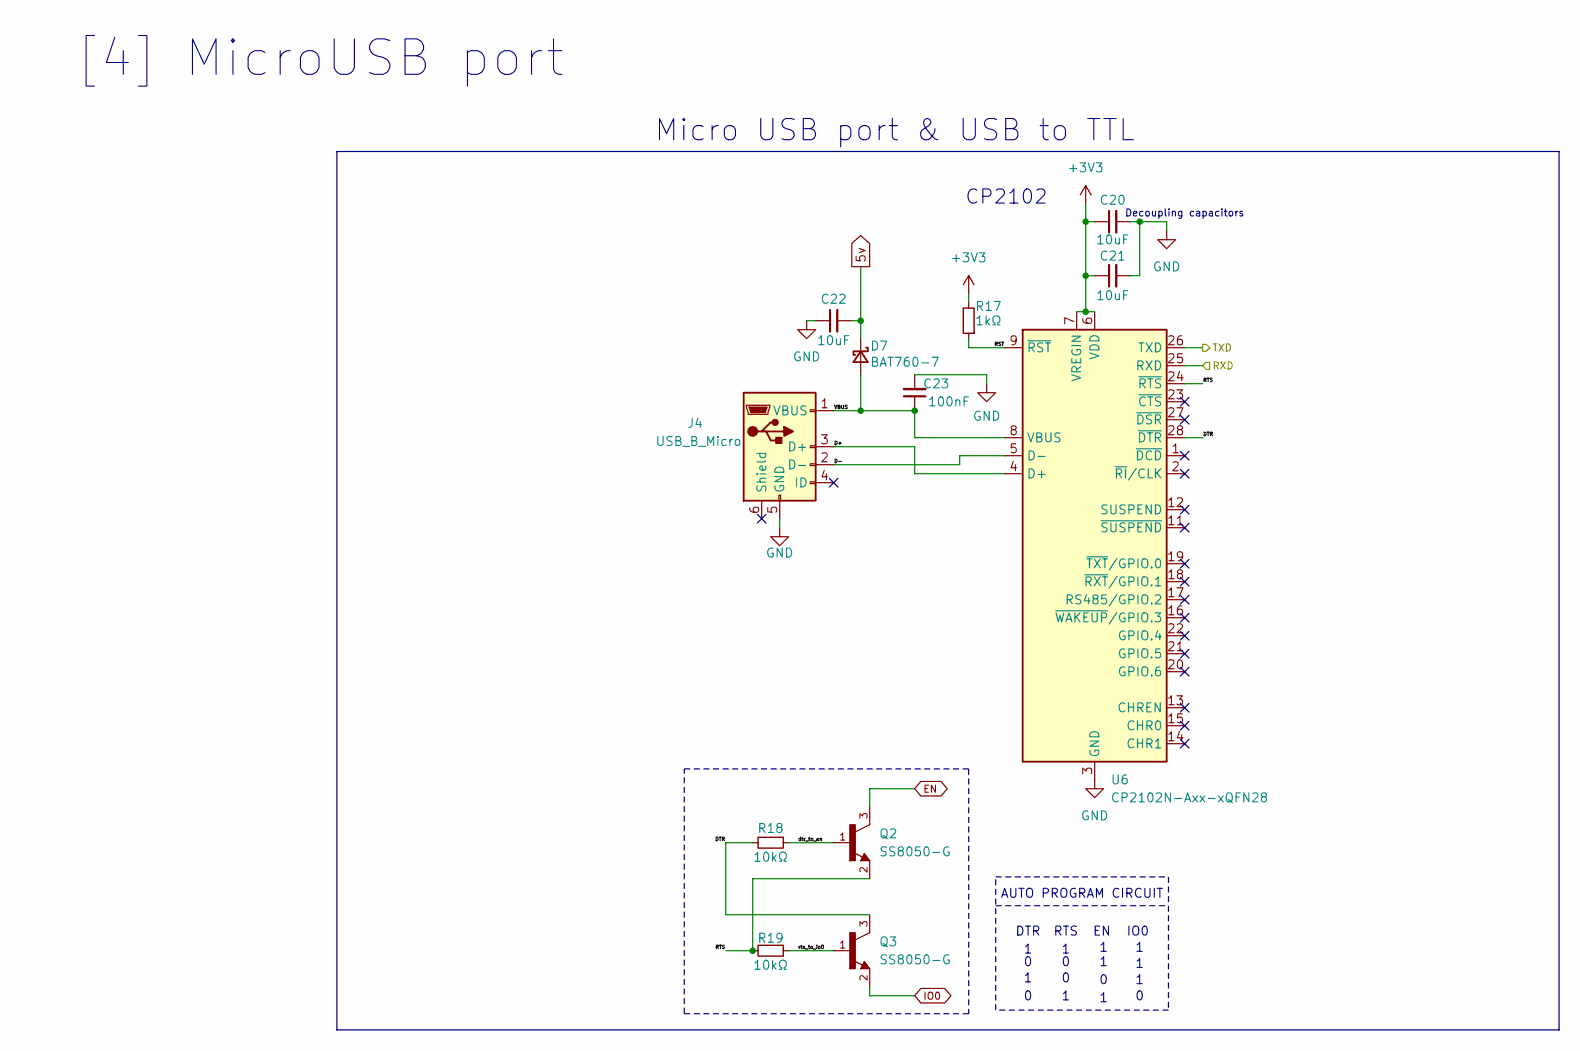
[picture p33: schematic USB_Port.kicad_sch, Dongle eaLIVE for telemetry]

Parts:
C20, C21, C22: 10uF; C_0805_2012Metric_Pad1.18x1.45mm_HandSolder; LCSC C15850
C23: 100nF; C_0805_2012Metric_Pad1.18x1.45mm_HandSolder; LCSC C49678
D7: BAT760-7; LCSC C124187
J4: USB_B_Micro; USB_Micro-B_Molex_47346-0001; LCSC C404968
Q2, Q3: SS8050-G; TRANS_SS8050-G; PARTREV A; LCSC C164885
R17: 1kΩ; R_0805_2012Metric_Pad1.20x1.40mm_HandSolder; LCSC C17513
R18, R19: 10kΩ; R_0805_2012Metric_Pad1.20x1.40mm_HandSolder; LCSC C191101
U6: CP2102N-Axx-xQFN28; QFN-28-1EP_5x5mm_P0.5mm_EP3.35x3.35mm; LCSC C964632

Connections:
5v: C22.2, D7.1 (K); also elsewhere on the board
+3V3: C20.1, C21.1, R17.2, U6.6 (VDD), U6.7 (VREGIN); also elsewhere on the board
/MicroUSB_Port/D+: J4.3 (D+), U6.4 (D+)
/MicroUSB_Port/D-: J4.2 (D-), U6.5 (D-)
/MicroUSB_Port/DTR: Q3.3, R18.2, U6.28 (~DTR)
/MicroUSB_Port/RST: R17.1, U6.9 (~RST)
/MicroUSB_Port/RTS: Q2.2, R19.2, U6.24 (~RTS)
/MicroUSB_Port/RXD: U6.25 (RXD); also elsewhere on the board
/MicroUSB_Port/TXD: U6.26 (TXD); also elsewhere on the board
/MicroUSB_Port/VBUS: C23.1, D7.2 (A), J4.1 (VBUS), U6.8 (VBUS)
/MicroUSB_Port/dtr_to_en: Q2.1, R18.1
/MicroUSB_Port/rts_to_io0: Q3.1, R19.1
EN: Q2.3; also elsewhere on the board
GND: C20.2, C21.2, C22.1, C23.2, J4.5 (GND), U6.3 (GND), U6.29 (GND); also elsewhere on the board
IO0: Q3.2; also elsewhere on the board

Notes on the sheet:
IO0
RTS
Decoupling capacitors
DTR
AUTO PROGRAM CIRCUIT
[4] MicroUSB port
CP2102
Micro USB port & USB to TTL

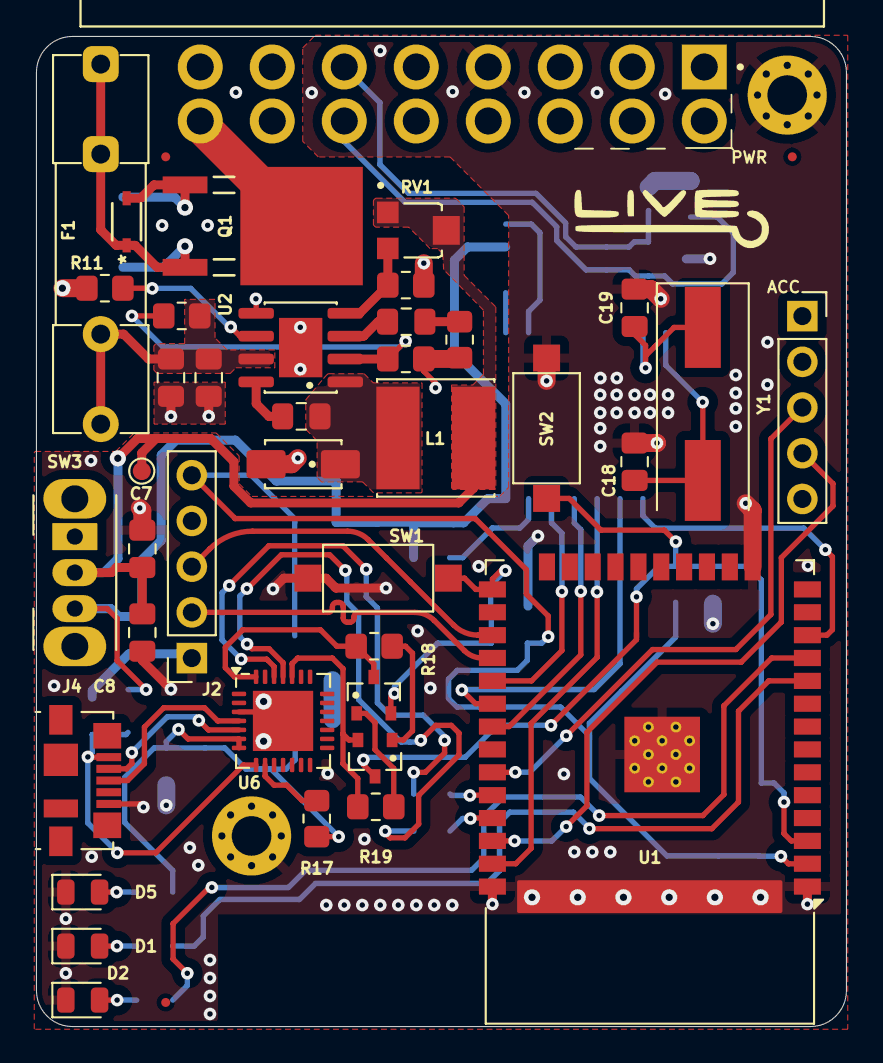
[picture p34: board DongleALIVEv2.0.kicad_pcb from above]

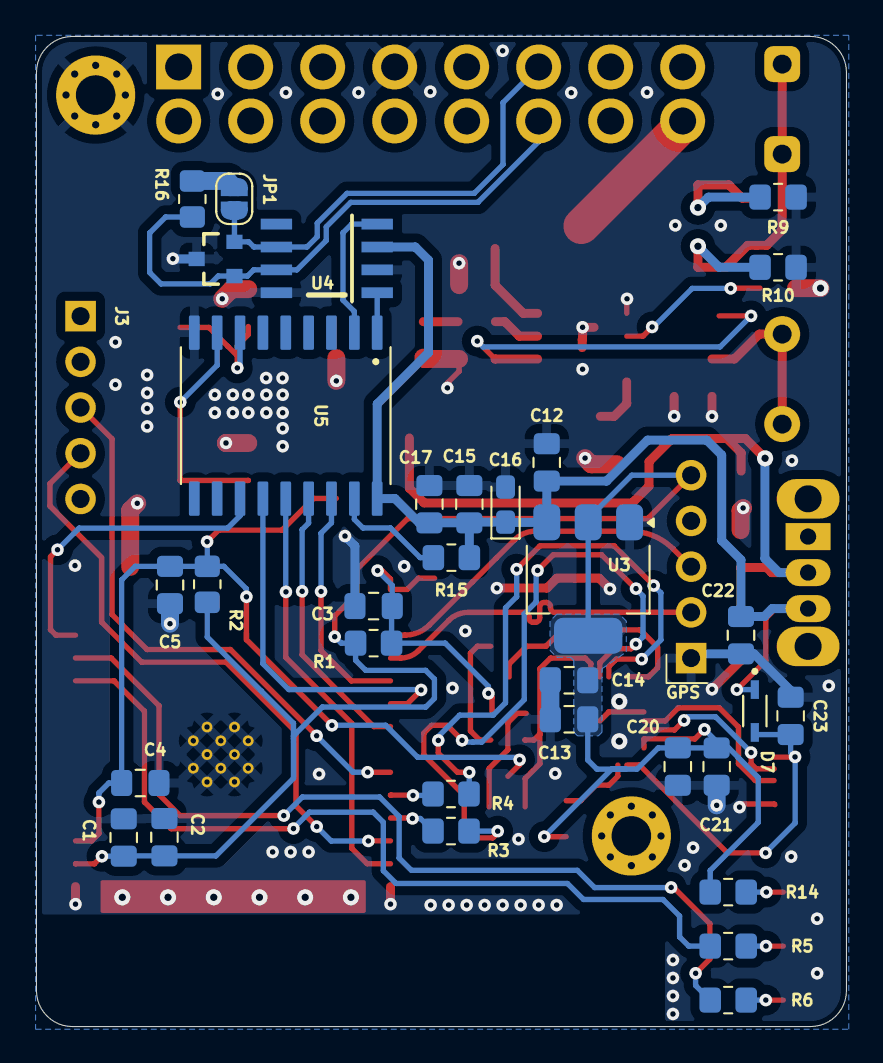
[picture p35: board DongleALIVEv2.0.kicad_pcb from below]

Board: 2 copper layers, 45.0 x 55.0 mm, 76 parts (32 on the bottom side), 51 nets.

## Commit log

2024-09-21 Layout Complete without BOM
    [1.5KE16A.step, 35WR10KLFTR.step, BAT760-7.step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]
2024-09-22 Fix tantalum capacitor & JLCPCB codes
    [CAN_controller.kicad_sch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]
2024-09-22 Testpoint to Vout
    [DongleALIVEv2.0-B_Cu.gbr, DongleALIVEv2.0-B_Mask.gbr, DongleALIVEv2.0-B_Paste.gbr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]
2024-09-24 Add step file of the PCB
    [DongleALIVEv2.0.kicad_pcb]
2024-10-02 Fix CP2102 connection
    [DongleALIVEv2.0-rounded.kicad_pcb, DongleALIVEv2.0.kicad_sch, Microcontroller.kicad_sch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]
2024-10-02 Update 01_Specs and Gerber
    [DongleALIVEv2.0-B_Cu.gbr, DongleALIVEv2.0-B_Mask.gbr, DongleALIVEv2.0-B_Paste.gbr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]
2024-11-02 V1 finished
    [DongleALIVEv2.0.kicad_pcb]
